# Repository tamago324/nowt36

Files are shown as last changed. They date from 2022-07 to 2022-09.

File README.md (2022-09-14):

# nowt36

以下の特徴を持ったキーボードです。

* 自然と手が置ける配列
* 一体型だけど分割型
* 片手5列
* ホットスワップ対応
* ミドルアクリルプレート対応 (オプション)
* アンダーグロー対応 (オプション)

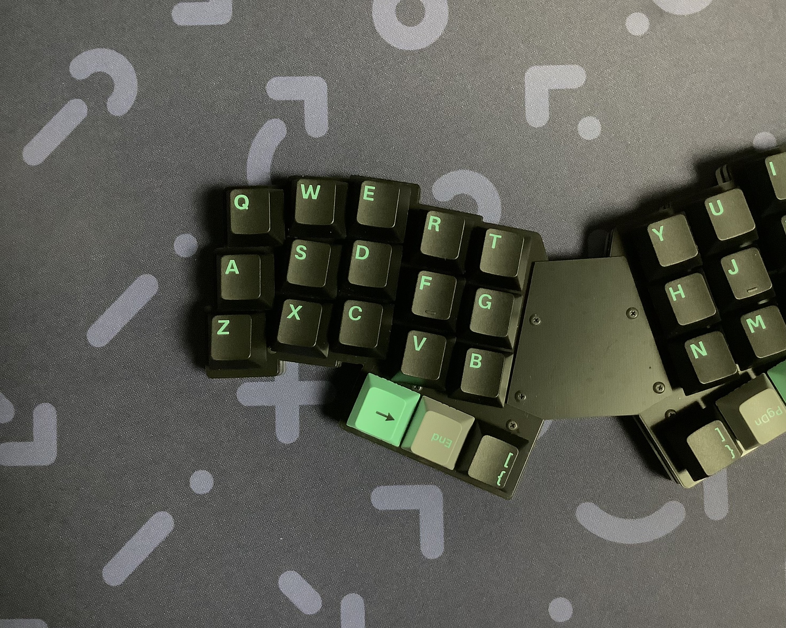
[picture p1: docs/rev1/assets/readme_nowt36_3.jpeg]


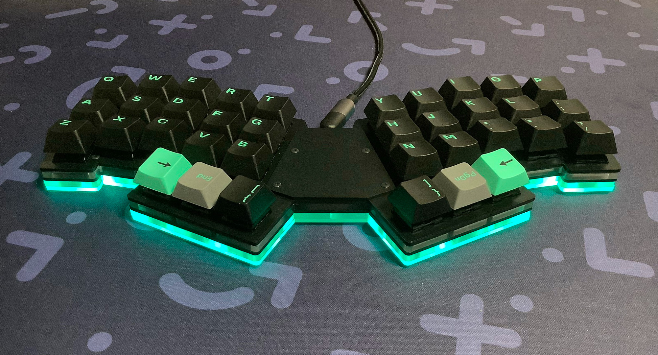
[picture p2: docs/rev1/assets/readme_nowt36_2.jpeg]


## LICENSE

<br />この 作品 は <a rel="license" href="http://creativecommons.org/licenses/by/4.0/">クリエイティブ・コモンズ 表示 4.0 国際 ライセンス</a>の下に提供されています。

> 帰属—適切なクレジットを表示し、ライセンスへのリンクを提供し、変更が行われたかどうかを示す必要があります。

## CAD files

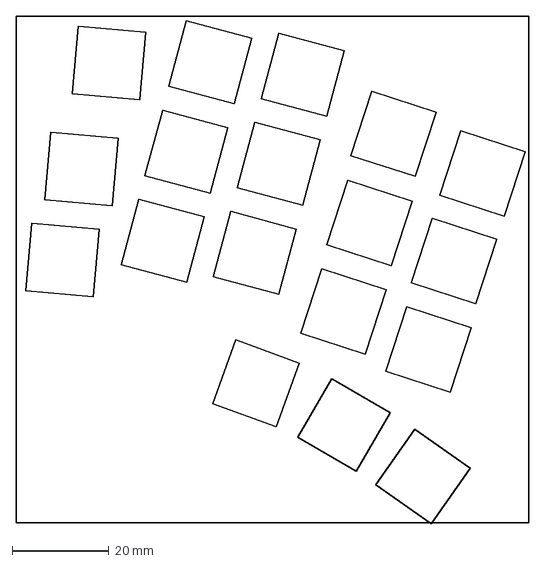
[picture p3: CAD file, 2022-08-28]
data/rev1/plate_base.dxf
105.8 x 104.8 mm

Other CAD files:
data/rev1/nowt36.FCStd

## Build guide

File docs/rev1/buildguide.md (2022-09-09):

# nowt36 ビルドガイド

nowt36 のビルドガイドです。

<details><summary>目次</summary><div>

<!-- vim-markdown-toc GFM -->

* [キットに含まれるもの](#キットに含まれるもの)
* [キット以外に必要なもの](#キット以外に必要なもの)
* [組み立て順序の確認](#組み立て順序の確認)
* [組み立て](#組み立て)
  * [1. ファームウェアの書き込み](#1-ファームウェアの書き込み)
    * [Remap で書き込む場合](#remap-で書き込む場合)
    * [LED の動作確認のため、LED機能をONにします。](#led-の動作確認のためled機能をonにします)
  * [2. (オプション) プレートの側面をペンで塗る](#2-オプション-プレートの側面をペンで塗る)
  * [3. (オプション) LEDの取り付け](#3-オプション-ledの取り付け)
  * [4. ダイオードのはんだ付け](#4-ダイオードのはんだ付け)
  * [5. ホットスワップソケットのはんだ付け](#5-ホットスワップソケットのはんだ付け)
  * [6. リセットスイッチのはんだ付け](#6-リセットスイッチのはんだ付け)
  * [7. (オプション) ミドルプレート (上) とトッププレートの間にシリコンシートを挟む](#7-オプション-ミドルプレート-上-とトッププレートの間にシリコンシートを挟む)
  * [8. トッププレートの端にスイッチを取り付ける](#8-トッププレートの端にスイッチを取り付ける)
  * [9. PCBにトッププレートとスイッチを取り付ける](#9-pcbにトッププレートとスイッチを取り付ける)
  * [10. ボトムプレートを取り付ける](#10-ボトムプレートを取り付ける)
  * [11. トッププレート側からネジ止めする](#11-トッププレート側からネジ止めする)
  * [12. ProMicro保護プレートを取り付ける](#12-promicro保護プレートを取り付ける)
  * [13. ゴム足を取り付ける](#13-ゴム足を取り付ける)
  * [14. キーキャップを取り付ける](#14-キーキャップを取り付ける)
  * [15. キーマップを変更する](#15-キーマップを変更する)
* [最後に](#最後に)

<!-- vim-markdown-toc -->

</div></details>

## キットに含まれるもの

| No. | 名前 | 数量 | 備考 |
|-----|---|---|---|
| 1 | PCB | 1枚 | メインPCB |
| 2 | トッププレート | 1枚 | スイッチをはめるFR4プレート |
| 3 | ボトムプレート | 1枚 | ボトムアクリルプレート |
| 8 | ProMicro 保護プレート | 1枚 | ProMicro 保護プレート。 |
| 9 | スイッチソケット | 36個 | [Kailh Switch Socket](https://shop.yushakobo.jp/products/a01ps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) |
| 10  | ダイオード | 36個 + 予備 | [1N4148W](https://shop.yushakobo.jp/collections/all-keyboard-parts/products/a0800di-02-100) |
| 11  | リセットスイッチ | 1個 | [タクトスイッチ](https://shop.yushakobo.jp/collections/all-keyboard-parts/products/a0800ts-01-1?variant=37665574977697) |
| 12  | M2 スペーサー 8mm (短いもの) | 10個 | トッププレートとボトムプレートを固定するためのスペーサー |
| 13  | M2 スペーサー 9.5mm (長いもの) | 4個 | ProMicro保護プレートとボトムプレートを固定するためのスペーサー |
| 14  | M2 ねじ 5mm | 28個 + 予備 | スペーサーを固定するネジ |
| 15  | アンダーグロー用LED | 10個 | [WS2812B](https://shop.yushakobo.jp/products/a0800ws-01-10?variant=37664848969889) |
| 16  | ゴム足 | 10個 | すべり止め用のゴム足 |

## キット以外に必要なもの

| 名前 | 数量 | 備考 |
|---|---|---|
| キースイッチ | 36個 | - |
| キーキャップ | 36個 | - |
| USBケーブル | 1個  | - |
| ProMicro | 1個  | - |
| コンスルー or ピンヘッダ | 2枚  | 高さが2.5mm以下のものを使用する必要があります。 |

オプションでミドルプレートをつけられます。

| 名前 | 数量 | 備考 |
|---|---|---|
| ミドルプレート (上) | 1枚 | ※1 |
| ミドルプレート (下) | 1枚 | ※1 |
| シリコンシート 0.5mm | 1枚 | トッププレートとミドルプレート (上) の間に挟むシリコンシート。[モノタロウなどで購入](https://www.monotaro.com/g/00279214/?monotaroNo=36295253) |
| シリコンカットサポートシート | 1枚 | シリコンシートを切り抜くときに使用する紙。([こちら](/data/rev1/silicon_cut_sheet/silicon_cut_sheet.svg)を印刷します。) |

※1 [こちら](https://shop.yushakobo.jp/collections/services/products/keyboard_acrylic_plate?variant=44579876995303)から遊舎工房で発注可能です。もとのデータは [こちら](/data/rev1/plate_data/middle_plate) にあるため、自由に加工しAnymanyさんのような他の業者に発注することも可能です。(厚さは **3mm** で発注してください。)

## 組み立て順序の確認

0. キットの内容物の確認
1. ファームウェアの書き込み
2. (オプション) プレートの側面をペンで塗る
3. (オプション) LEDの取り付け
4. ダイオードのはんだ付け
5. ホットスワップソケットのはんだ付け
6. リセットスイッチのはんだ付け
7. (オプション) ミドルプレート (上) とトッププレートの間にシリコンシートを挟む
8. トッププレートの端にスイッチを取り付ける
9. PCBにトッププレートとスイッチを取り付ける
10. ボトムプレートを取り付ける
11. トッププレート側からネジ止めする
12. ProMicro保護プレートを取り付ける
13. ゴム足を取り付ける
14. キーキャップを取り付ける
15. キーマップを変更する

## 組み立て

### 1. ファームウェアの書き込み

REMAP か [QMK](https://github.com/tamago324/qmk_firmware/tree/nowt36/keyboards/tamago324/nowt36) を使用して、ファームウェアを書き込みます。
LEDをはんだ付けする前に Remap でファームウェアを書き込んでおくことで、LED の取付時に1つ1つ確認することができます。

<details><summary>Remap で書き込む場合</summary><div>

#### Remap で書き込む場合

LED を取り付ける場合、Remap でファームウェアを書き込み、LED機能をONにしておくとLEDが正しくはんだ付けできているかの確認が簡単になるのでおすすめです。

> サリチル酸さんの[こちら](https://salicylic-acid3.hatenablog.com/entry/remap-manual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,%E3%83%95%E3%82%A1%E3%83%BC%E3%83%A0%E3%82%A6%E3%82%A7%E3%82%A2%E3%82%92%E6%9B%B8%E3%81%8D%E8%BE%BC%E3%82%80,-%E3%82%AD%E3%83%BC%E3%83%9C%E3%83%BC%E3%83%89%E3%82%AB%E3%82%BF%E3%83%AD%E3%82%B0%E6%A9%9F%E8%83%BD)の記事を参考に手順を記述しています。

https://remap-keys.app/ にアクセスします。 

KEYBOARD CATALOG をクリックします。

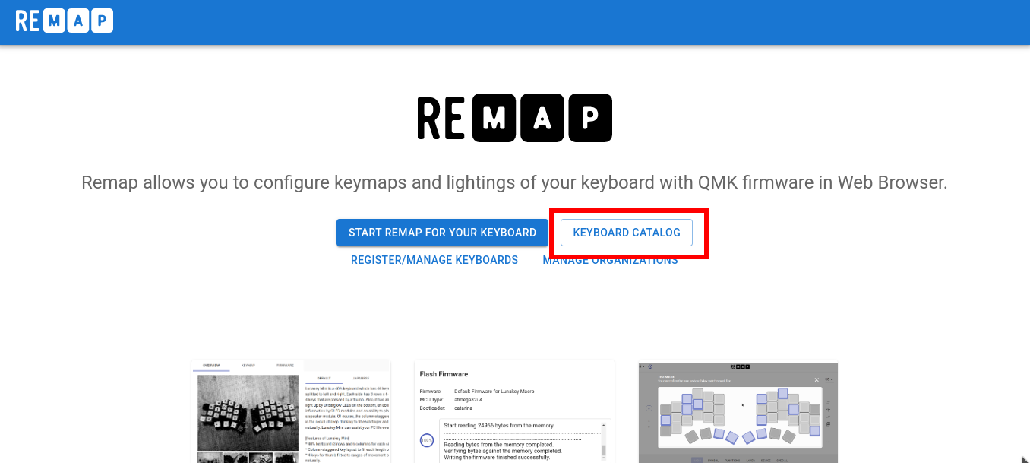
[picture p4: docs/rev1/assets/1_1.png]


Keyboard name の入力欄に `nowt36` と入力し、Search をクリックし、検索結果の nowt36 をクリックします。

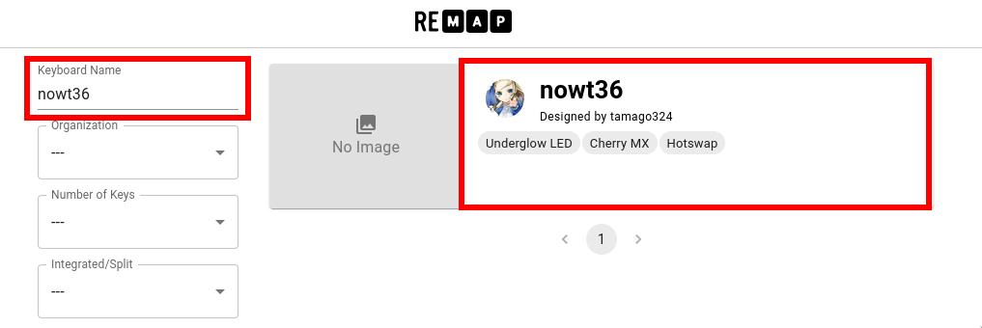
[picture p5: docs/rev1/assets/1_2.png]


FIRMWARE をクリックします。

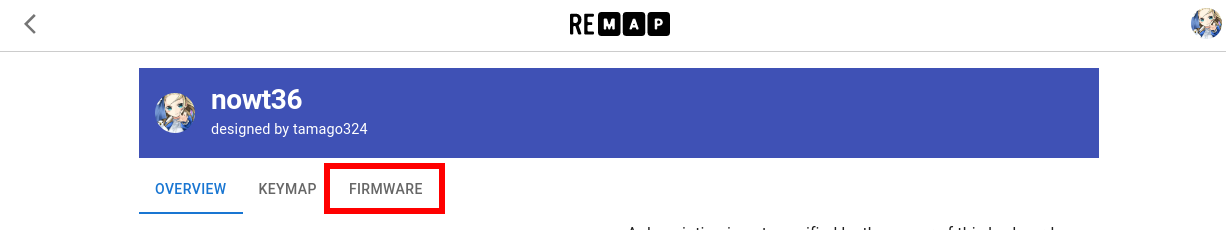
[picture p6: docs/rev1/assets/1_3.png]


FLASH をクリック

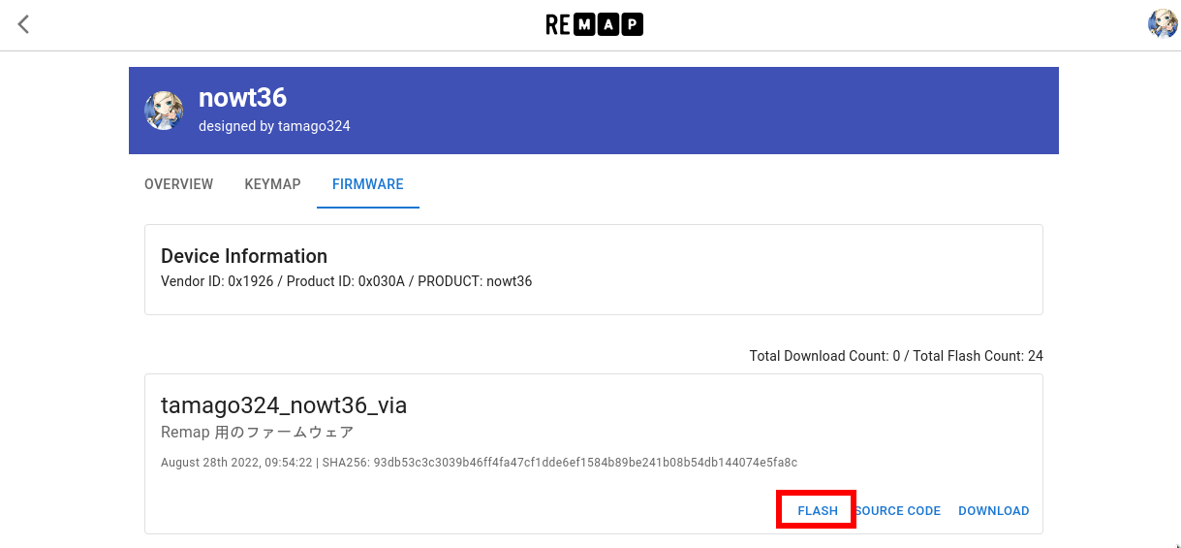
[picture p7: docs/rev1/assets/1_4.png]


ダイアログが表示されたら FLASH をクリックします。

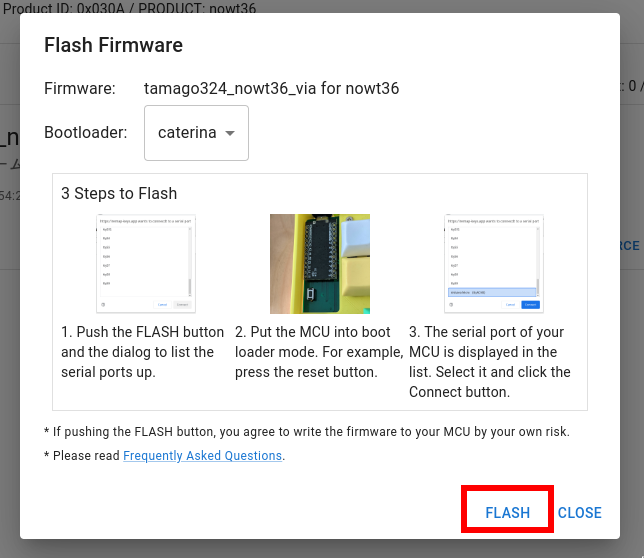
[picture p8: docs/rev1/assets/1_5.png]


remap-keys.app がシリアルポートへの接続を要求しています という表示が出たら、ピンセットでProMicro の`GND`と`RST`を2回素早く押します。

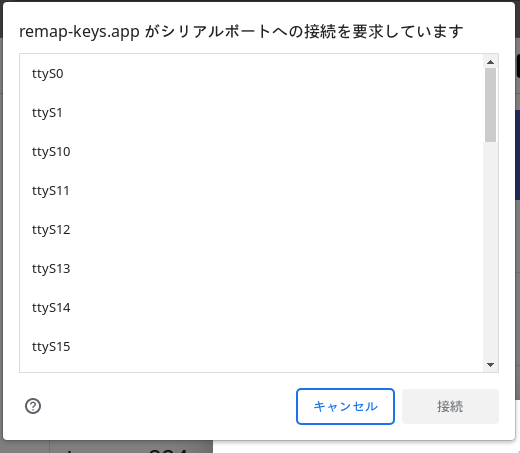
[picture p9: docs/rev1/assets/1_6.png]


ProMicro が表示されたら、それを選択し、接続ボタンをクリックします。  

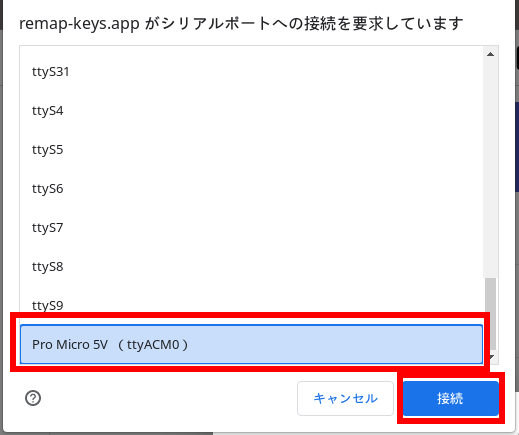
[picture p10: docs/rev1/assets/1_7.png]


少し時間が立つとファームウェアの書き込みが完了します。

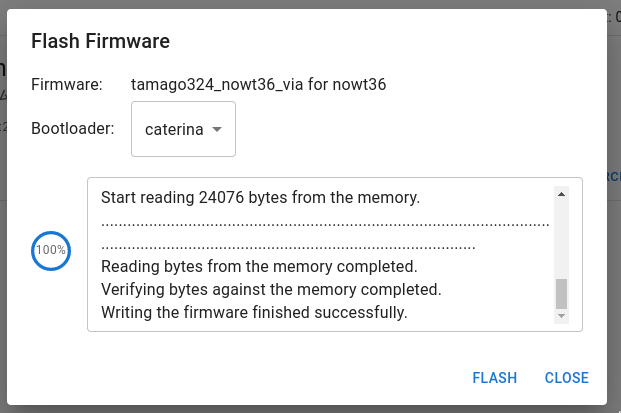
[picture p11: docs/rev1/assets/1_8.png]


#### LED の動作確認のため、LED機能をONにします。

https://remap-keys.app/ にアクセスします。

`START REMAP FOR YOUR KEYBOARD` をクリックします。

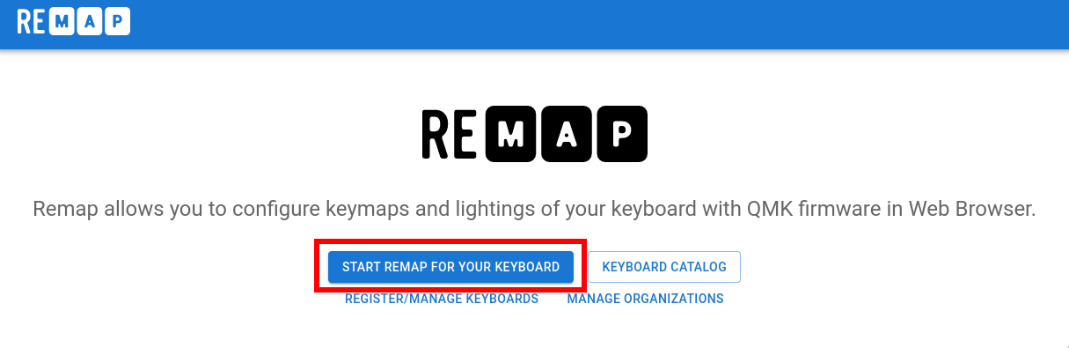
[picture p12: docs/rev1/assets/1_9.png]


`+ KEYBAORD` をクリックします。

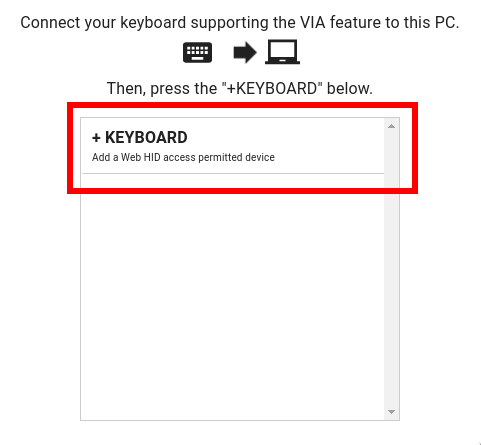
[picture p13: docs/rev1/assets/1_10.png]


`tamago324 nowt36` をクリックします。

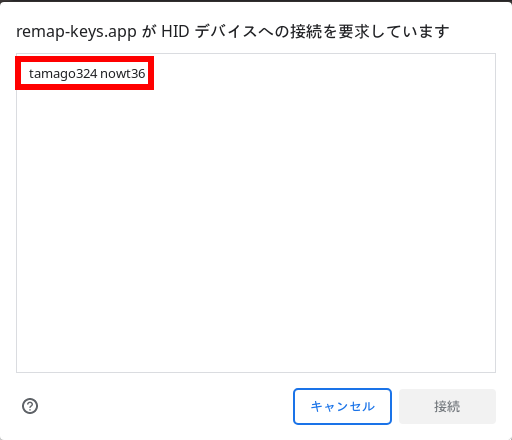
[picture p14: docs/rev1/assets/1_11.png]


`Lightning` をクリック、

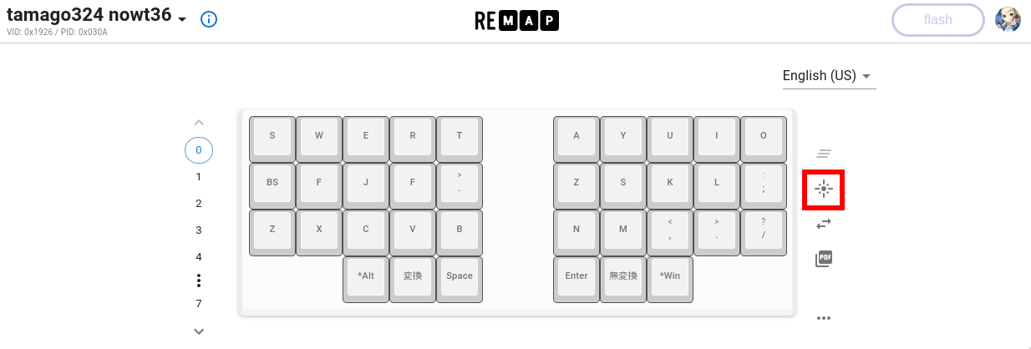
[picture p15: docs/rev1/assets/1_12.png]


`EffectMode` を `Solid color` を選択します。

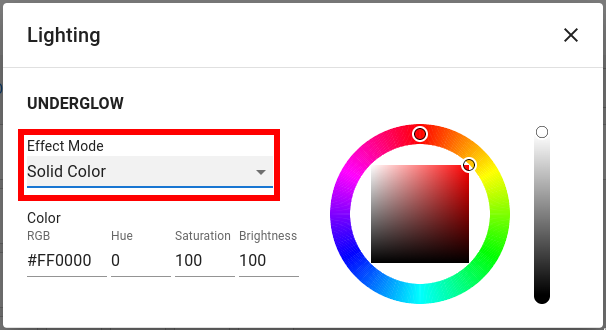
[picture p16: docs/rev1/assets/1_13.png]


以上で、LED の確認のためのファームウェアの書き込みは完了です。

</div></details>

### 2. (オプション) プレートの側面をペンで塗る

PCB と ボトムプレートの側面をペンで塗るときれいに仕上げられます。

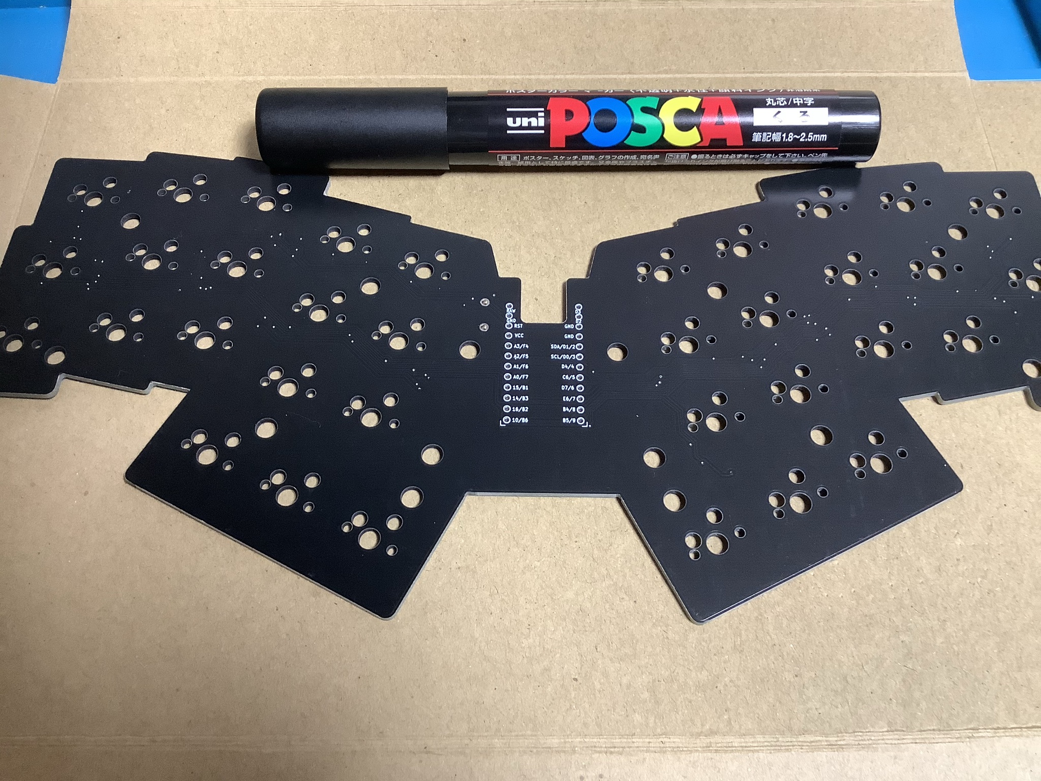
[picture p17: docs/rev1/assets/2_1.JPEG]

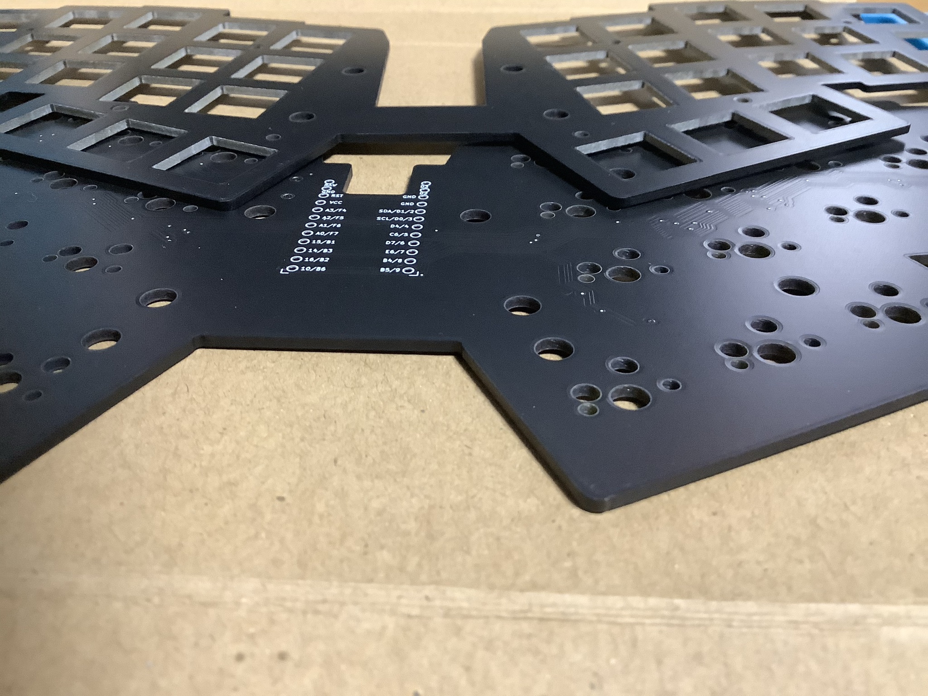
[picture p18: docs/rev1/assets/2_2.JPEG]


### 3. (オプション) LEDの取り付け

PCBの裏の D37 から時計回りにLEDを9個 (D37〜D45) をはんだ付けします。 
PCBの裏のはんだ付けが終わったら PCB の表面の D46 にLEDを1個はんだ付けします。
「PCBのシルクの角」と「LEDのかけている部分」が同じ位置になるようにはんだ付けします。
はんだごての温度は低め (270℃〜300℃) に設定し、作業します。

1つLEDをはんだ付けするたびにUSBを接続し、LED が光ることを確認することをおすすめします。

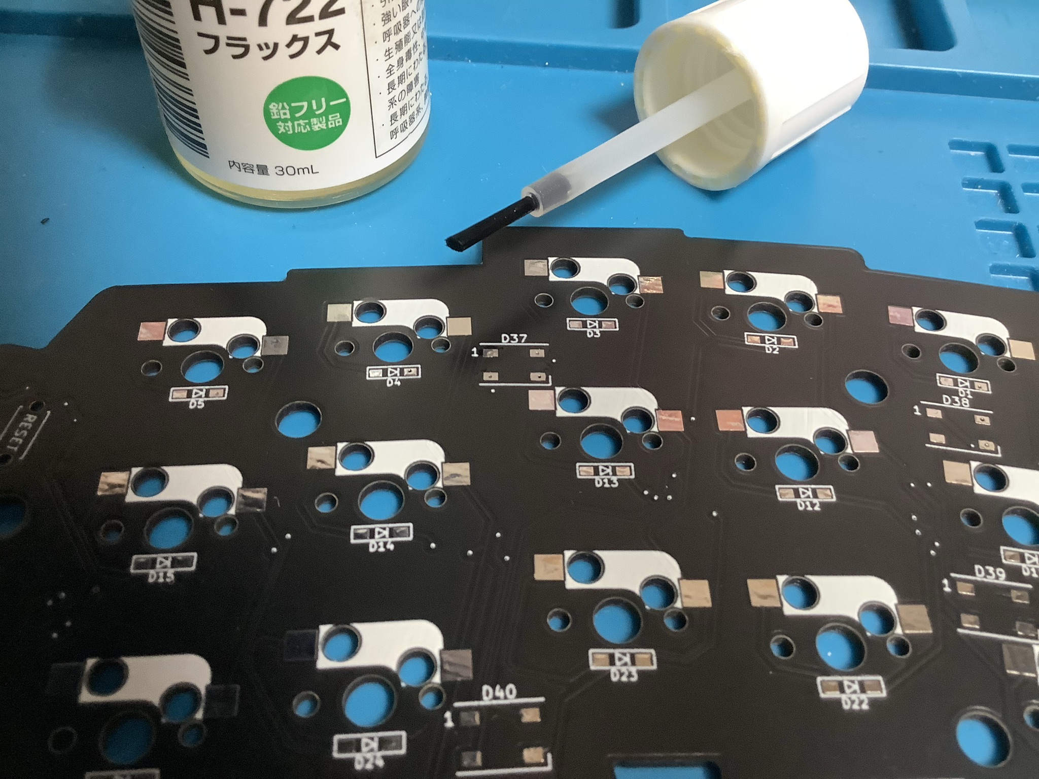
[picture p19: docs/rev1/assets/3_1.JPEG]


PCBのシルクの角 に予備ハンダをします。

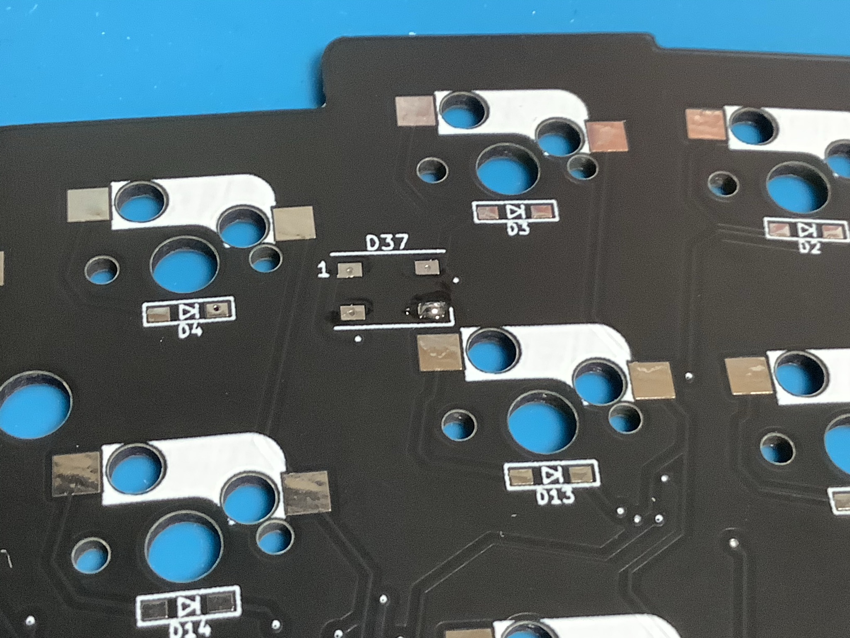
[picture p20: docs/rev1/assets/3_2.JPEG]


PCBのシルクの角 と LEDのかけている部分が同じ位置になるようにはんだ付けします。

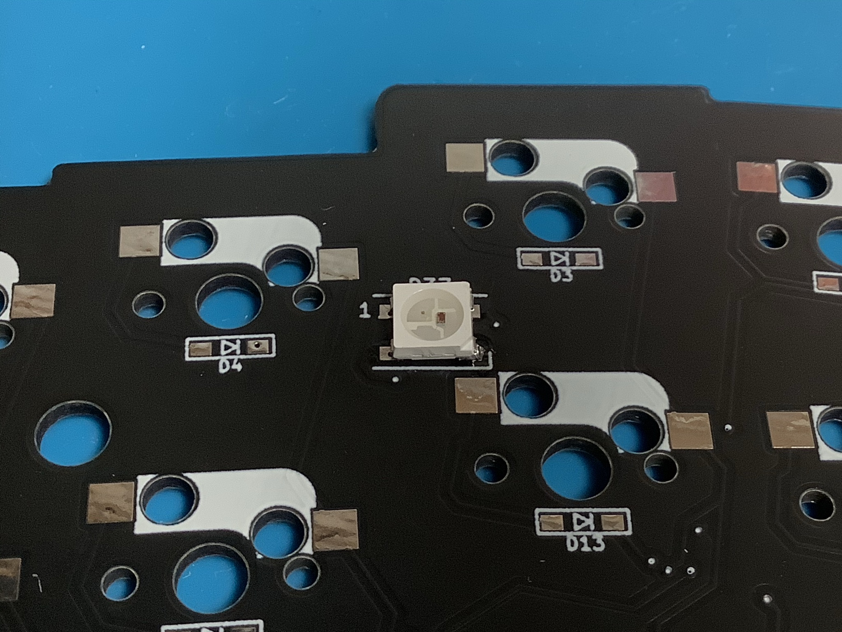
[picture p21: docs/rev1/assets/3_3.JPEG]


それ以外の部分をはんだ付けします。

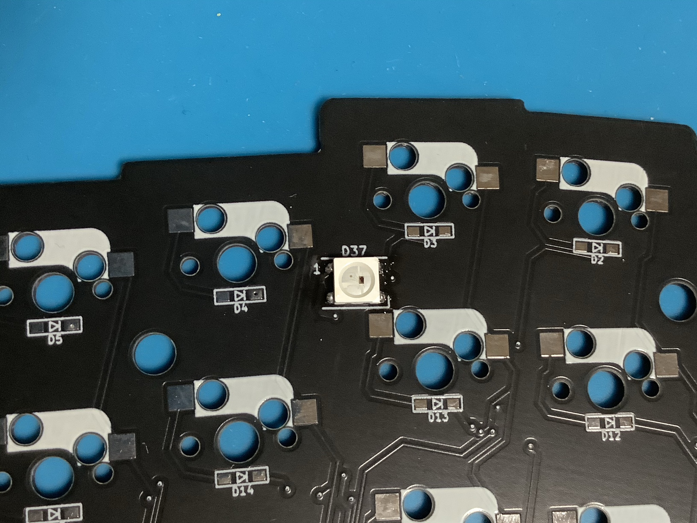
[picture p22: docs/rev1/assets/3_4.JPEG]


4箇所はんだ付けし終わったらUSBを接続し、LEDが光ることを確認します。
(※ REMAP で LED をONにしておくことで簡単に光ることが確認できます。)

また、LED をはんだ付けするときはUSBケーブルを外してください。

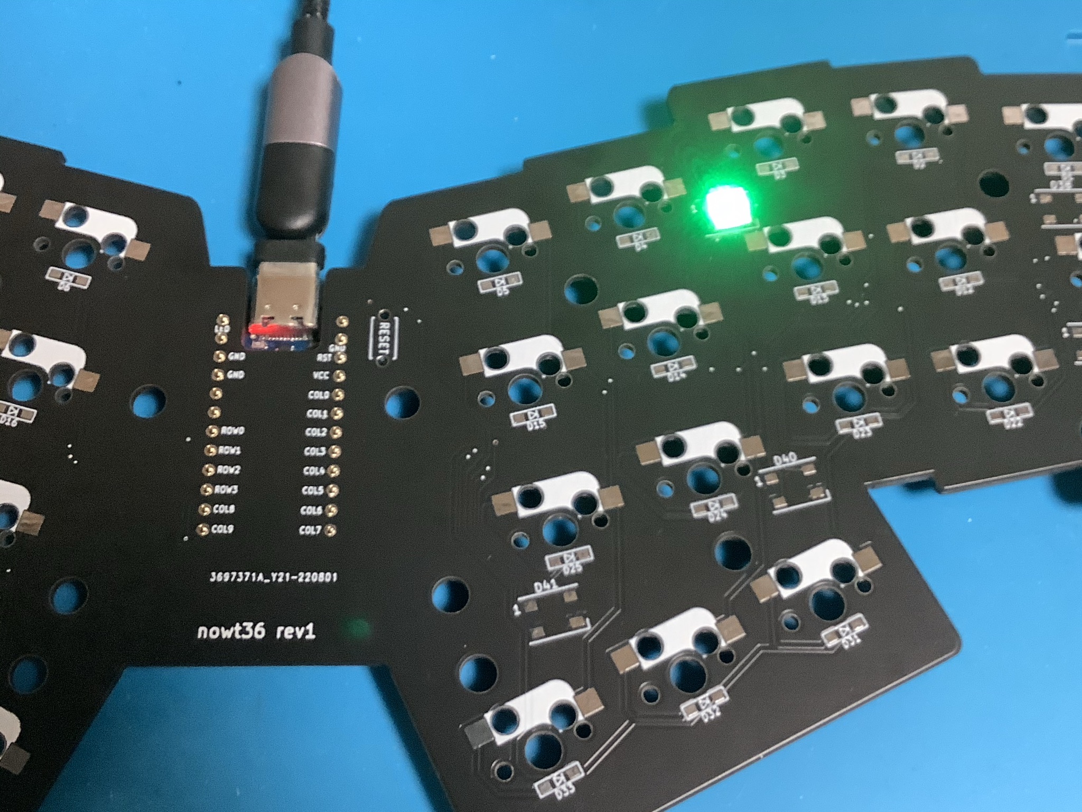
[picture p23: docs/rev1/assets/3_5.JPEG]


10個の LED をはんだ付けします。

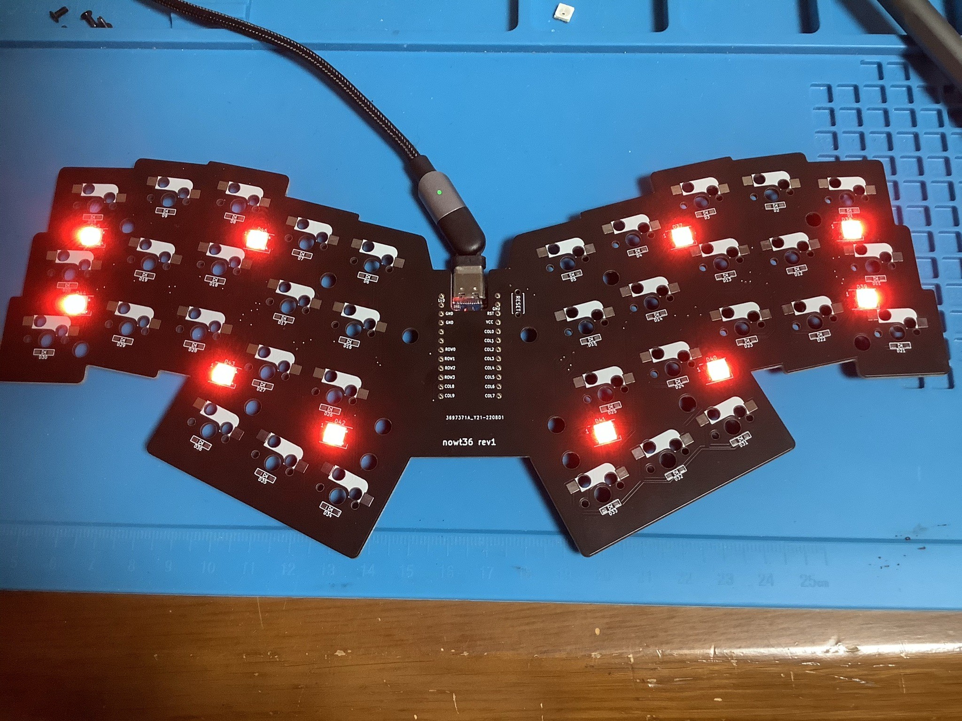
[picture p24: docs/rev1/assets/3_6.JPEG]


### 4. ダイオードのはんだ付け

PCBの裏にダイオードを36個はんだ付けします。
「PCBのシルクの線」と「ダイオードの線」が一致するようにはんだ付けします。
はんだごての温度は320℃くらいに設定し作業します。

片側に予備ハンダを行い、
ピンセットを使用して、はんだ付けを行い、
もう片方もはんだ付けします。

すべてのダイオードのはんだ付けが終わったら、すべてのダイオードが同じ向きになっていることを確認してください。

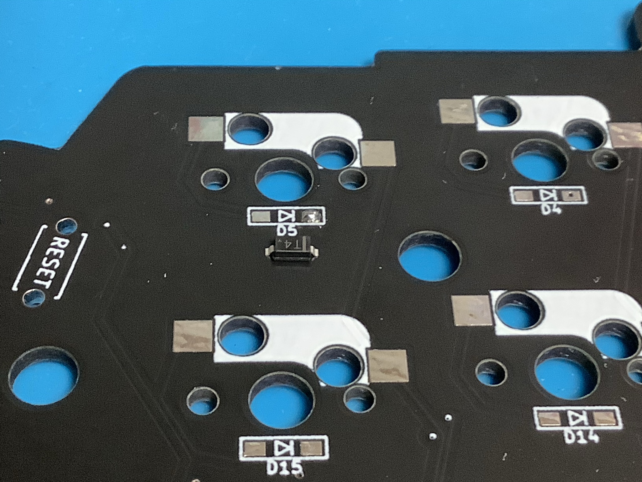
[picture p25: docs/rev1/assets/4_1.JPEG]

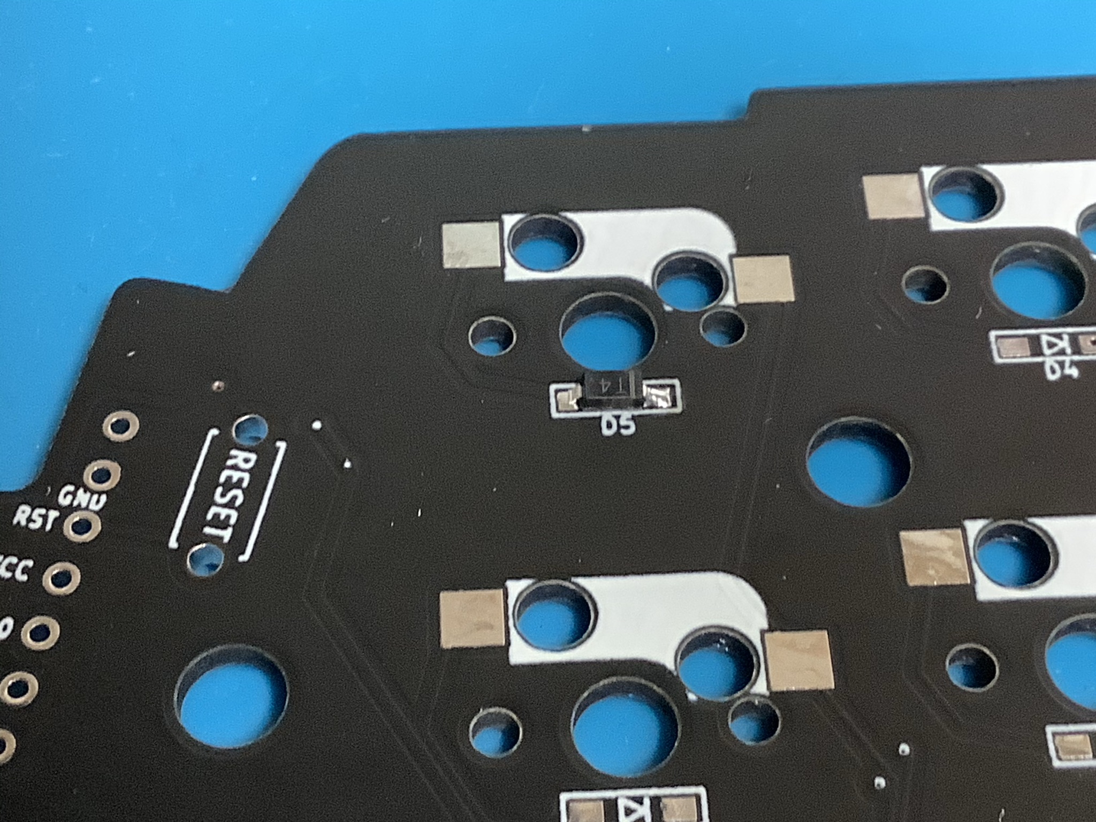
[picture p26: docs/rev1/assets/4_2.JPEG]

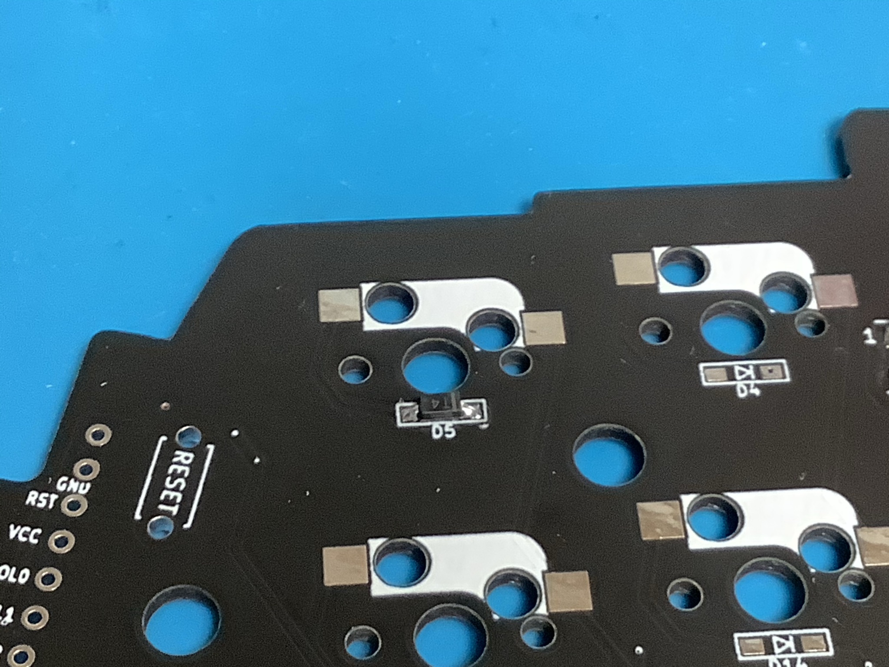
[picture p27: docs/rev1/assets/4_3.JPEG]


### 5. ホットスワップソケットのはんだ付け

PCBの裏にスイッチソケットを36個はんだ付けします。
PCBのシルクが隠れるようにはんだ付けします。
はんだごての温度は320℃くらいに設定し作業します。

片側に予備ハンダを行い、
スイッチソケットを置いて、はんだ付けします。
もう片方もはんだ付けします。

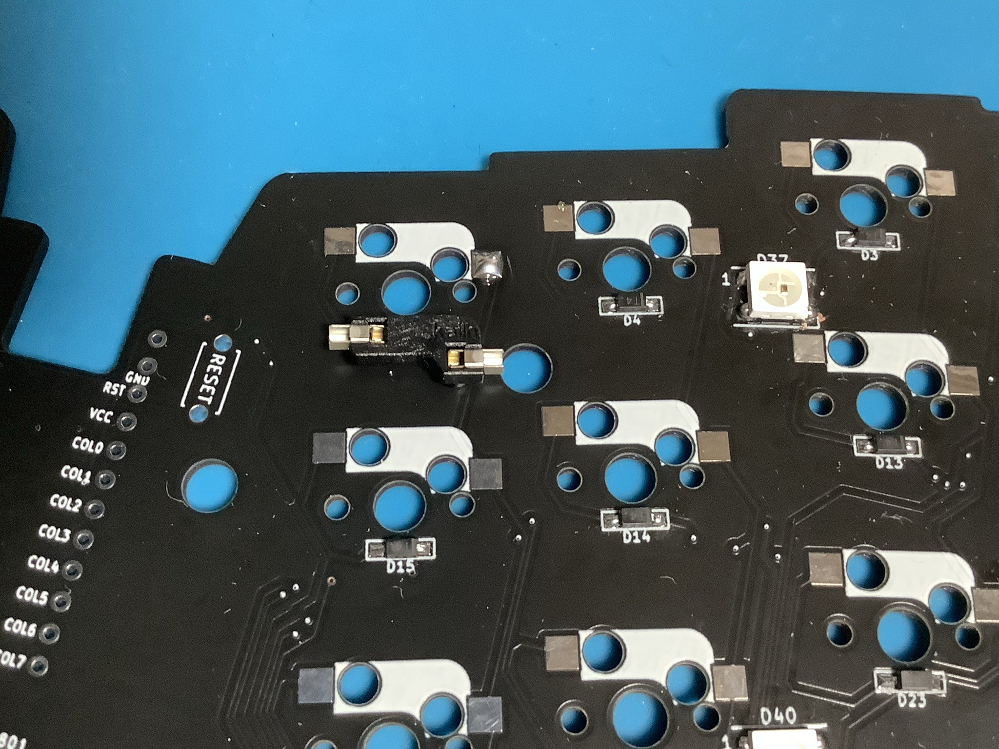
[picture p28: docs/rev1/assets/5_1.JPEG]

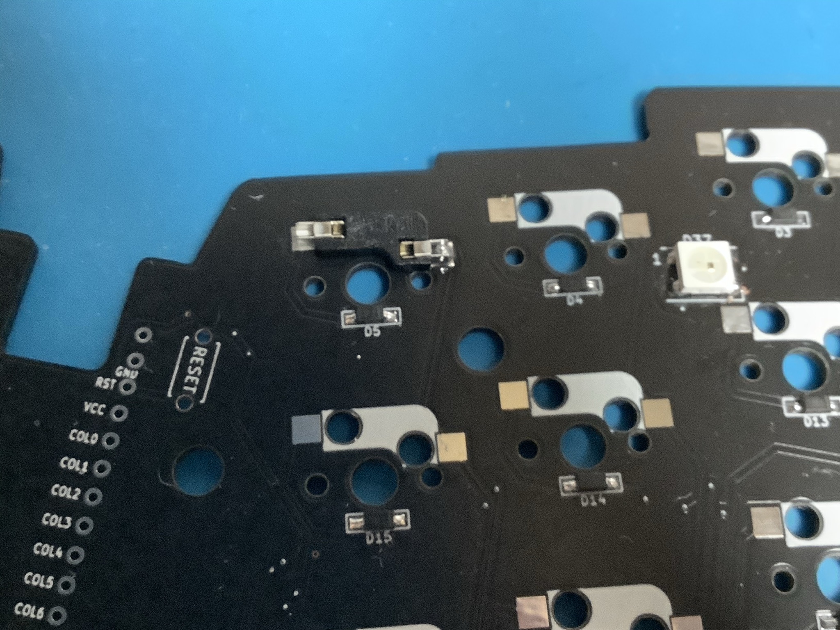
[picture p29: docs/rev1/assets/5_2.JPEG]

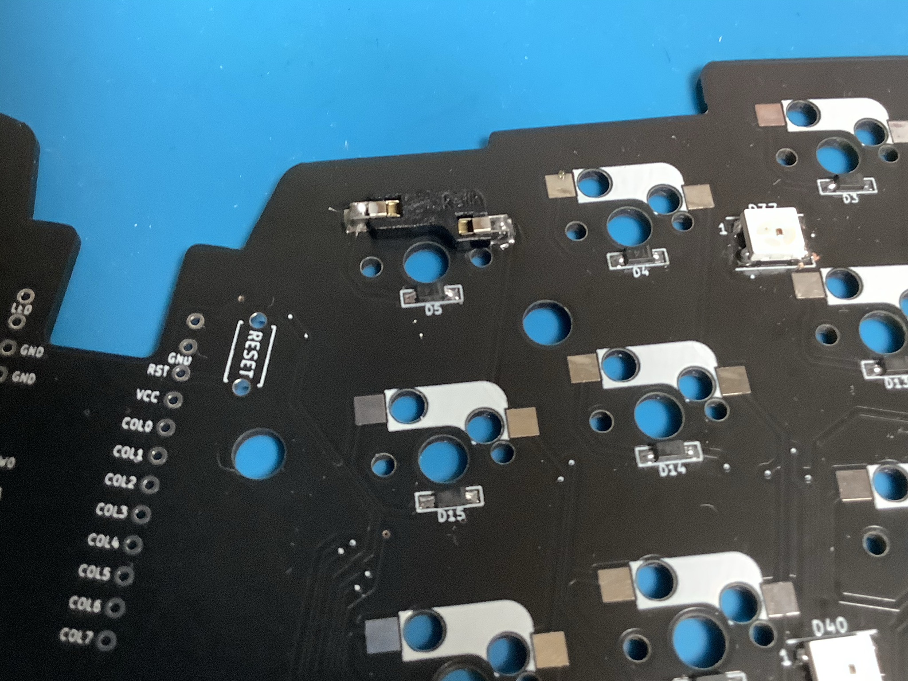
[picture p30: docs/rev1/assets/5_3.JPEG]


### 6. リセットスイッチのはんだ付け

PCBの裏から RESET という文字が隠れるようにリセットスイッチを差し込みます。
PCBの表に出ている足をはんだ付けします。

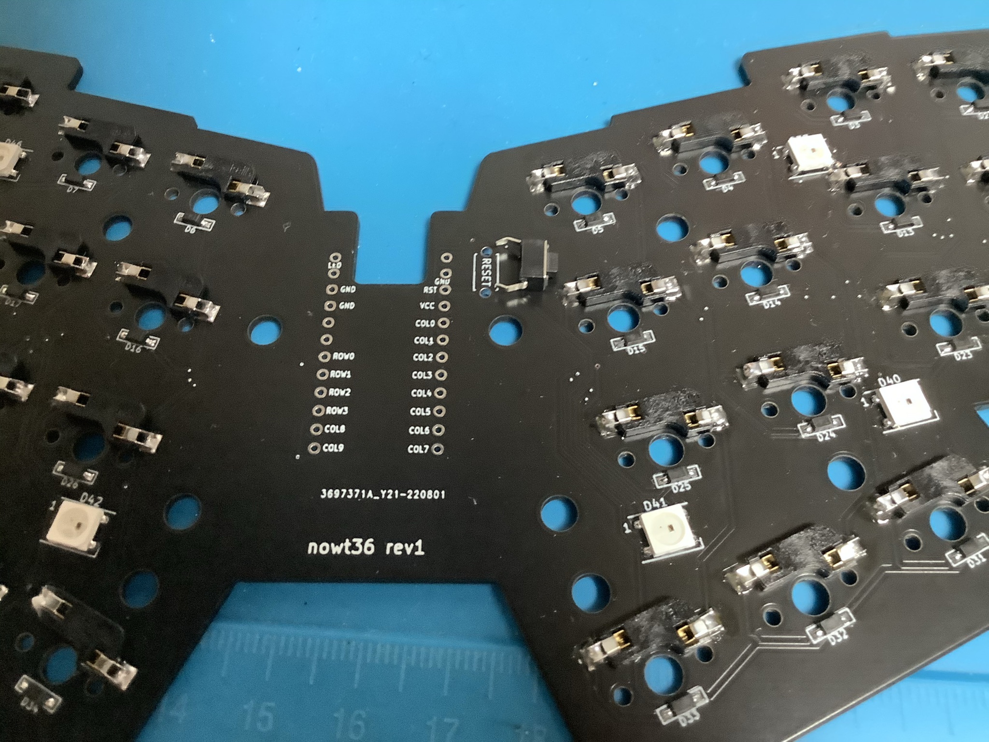
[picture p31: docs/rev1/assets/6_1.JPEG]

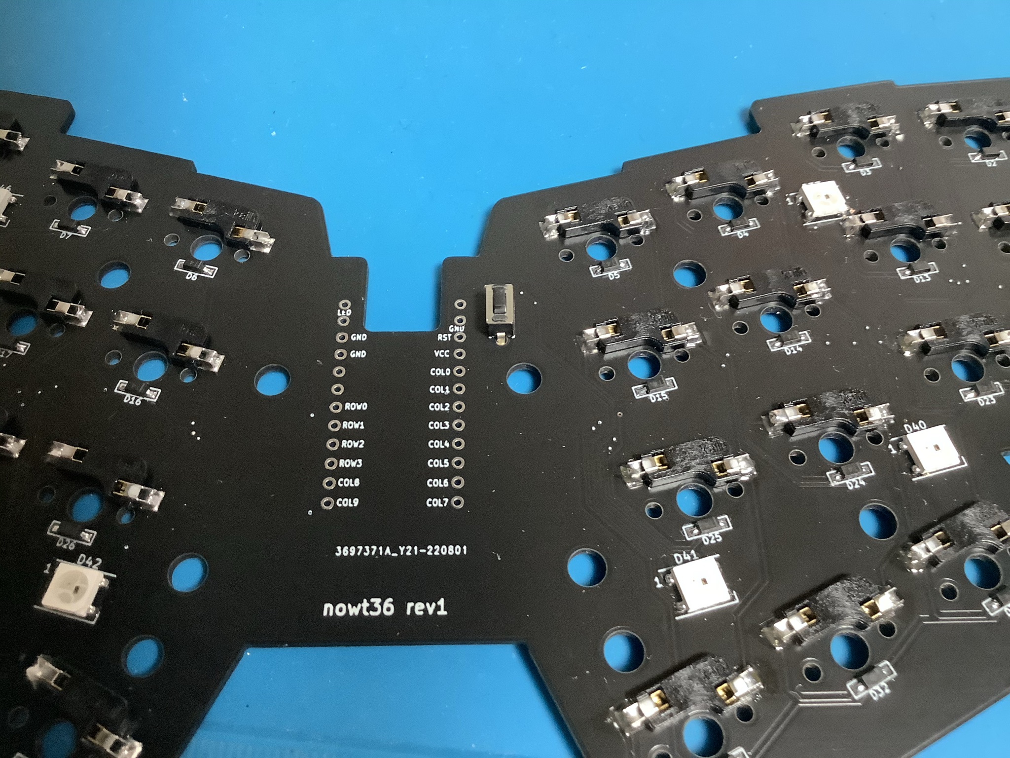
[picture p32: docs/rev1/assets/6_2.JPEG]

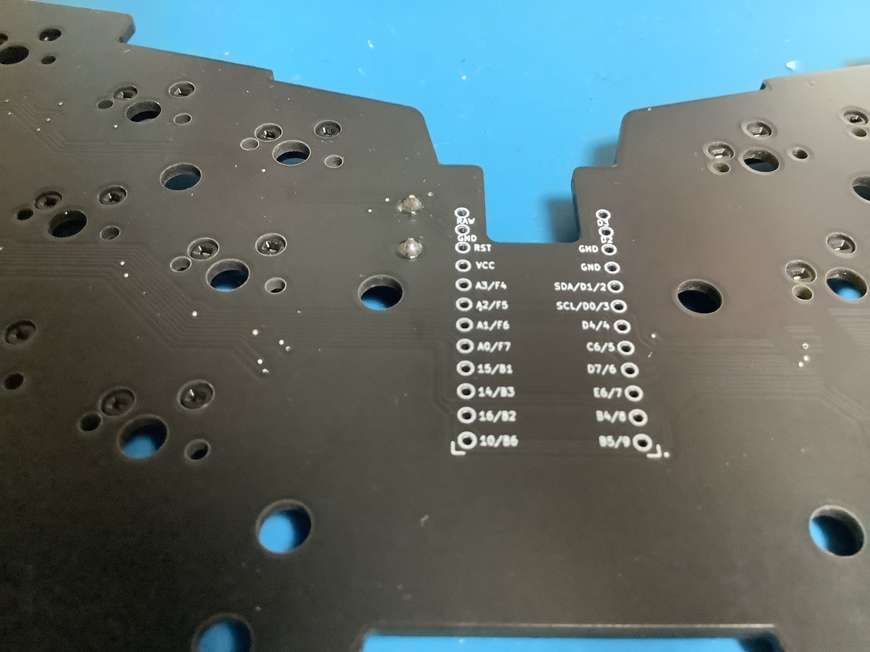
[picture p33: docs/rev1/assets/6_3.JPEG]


### 7. (オプション) ミドルプレート (上) とトッププレートの間にシリコンシートを挟む

オプションでミドルプレートをつけることができます。

<details><summary>手順</summary><div>

[シリコンカットサポートシート](/data/rev1/silicon_cut_sheet/silicon_cut_sheet.svg) をA4用紙で印刷します。

以下の手順でミドルプレート (上) とトッププレートの間にシリコンシートを挟みます。  
最初にシリコンカットサポートシート がミドルプレート (上) と同じサイズで印刷されていることを確認します。  
同じサイズだった場合、以下の手順を実施します。

1. シリコンシートについている保護シートを両面剥がします。

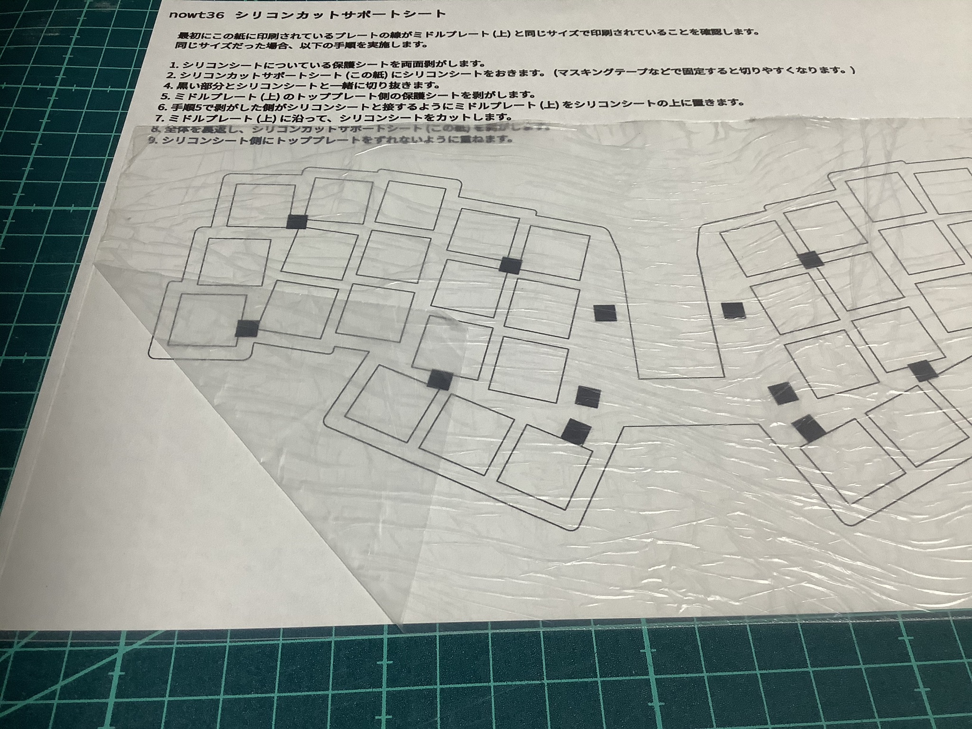
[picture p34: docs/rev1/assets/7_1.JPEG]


2. シリコンカットサポートシートにシリコンシートをおきます。 (マスキングテープなどで固定すると切りやすくなります。)

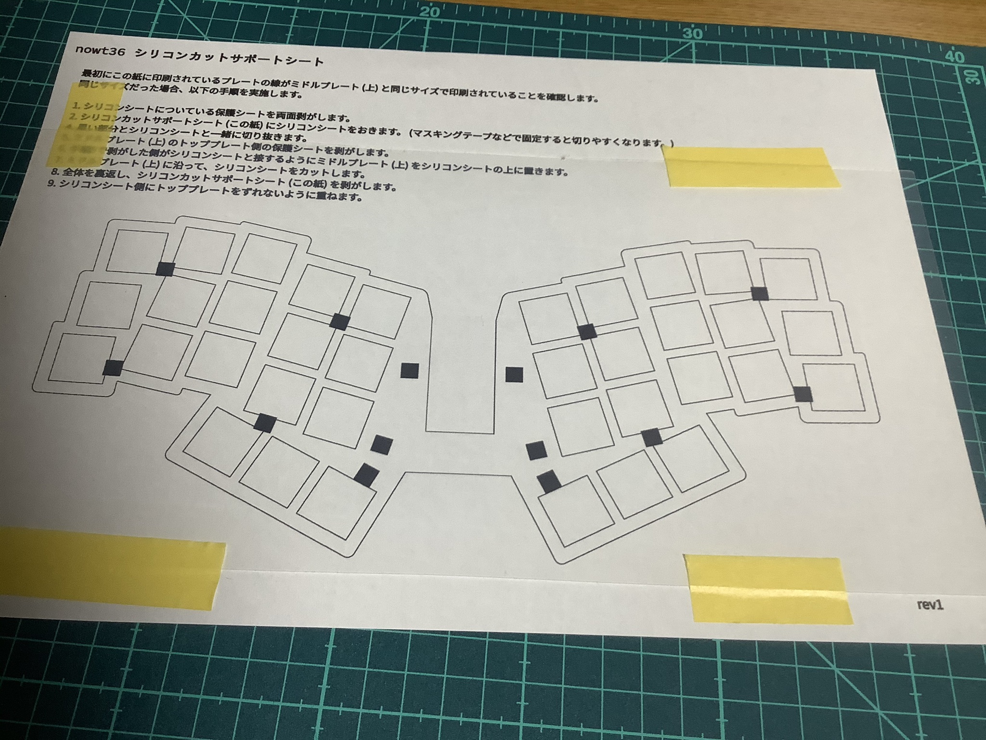
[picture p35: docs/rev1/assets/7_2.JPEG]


3. 黒い部分をシリコンシートと一緒に切り抜きます。

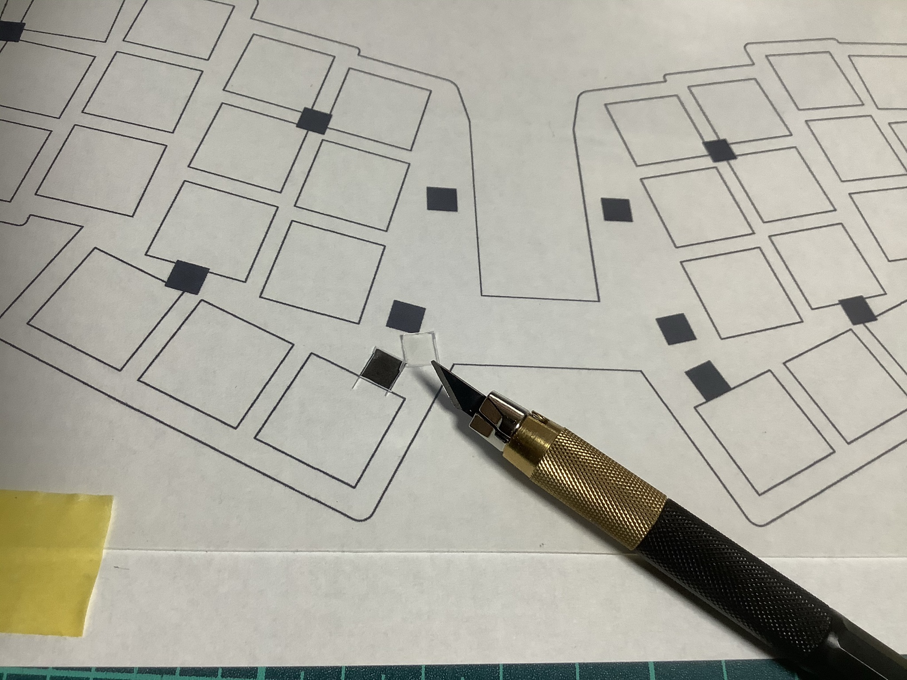
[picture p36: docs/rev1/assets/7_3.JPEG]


4. ミドルプレート (上) のトッププレート側の保護シートを剥がします。

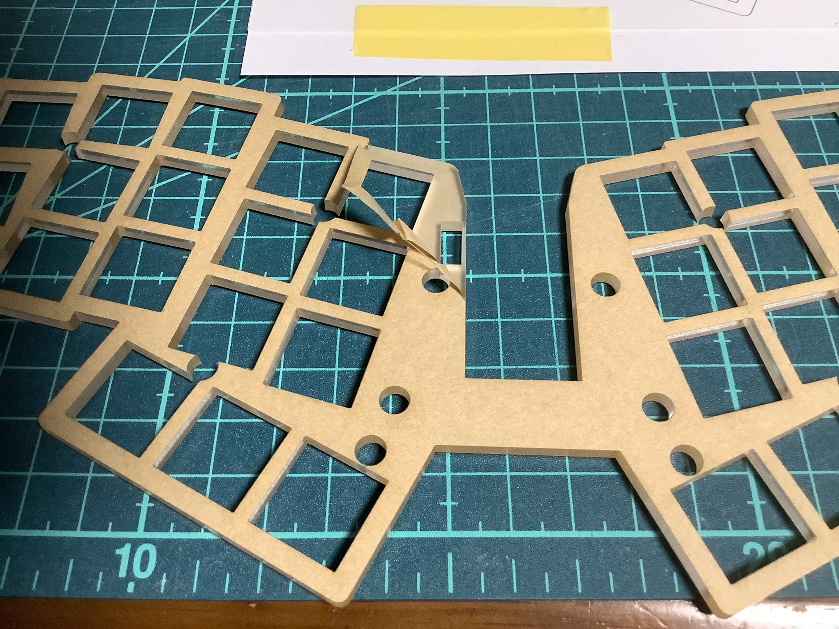
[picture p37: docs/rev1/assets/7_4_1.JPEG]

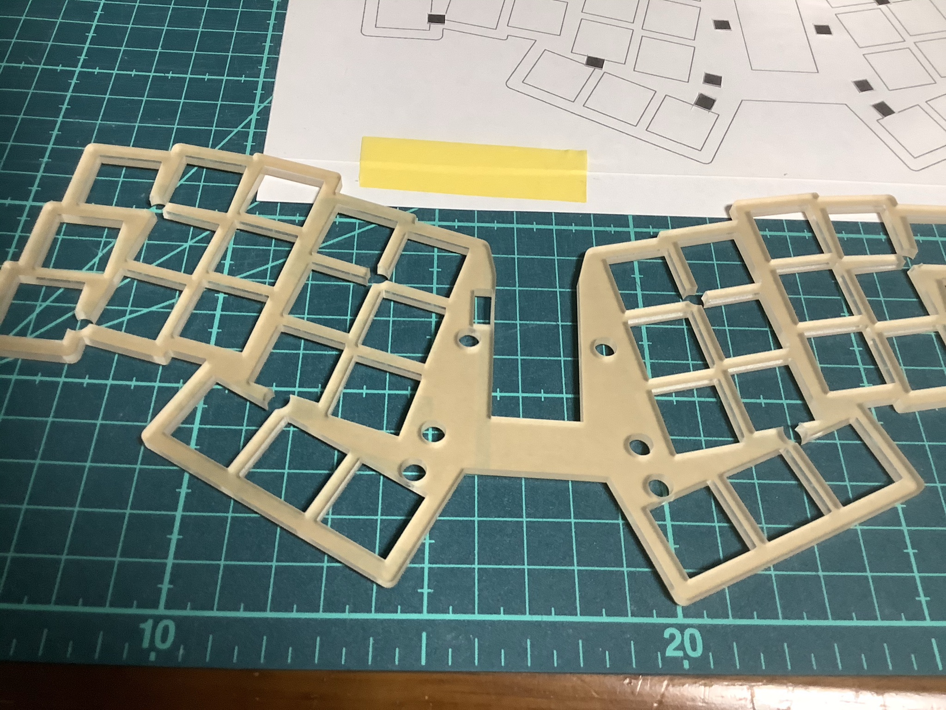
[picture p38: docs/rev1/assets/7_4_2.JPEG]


5. 手順5で剥がした側がシリコンシートと接するようにミドルプレート (上) をシリコンシートの上に置きます。

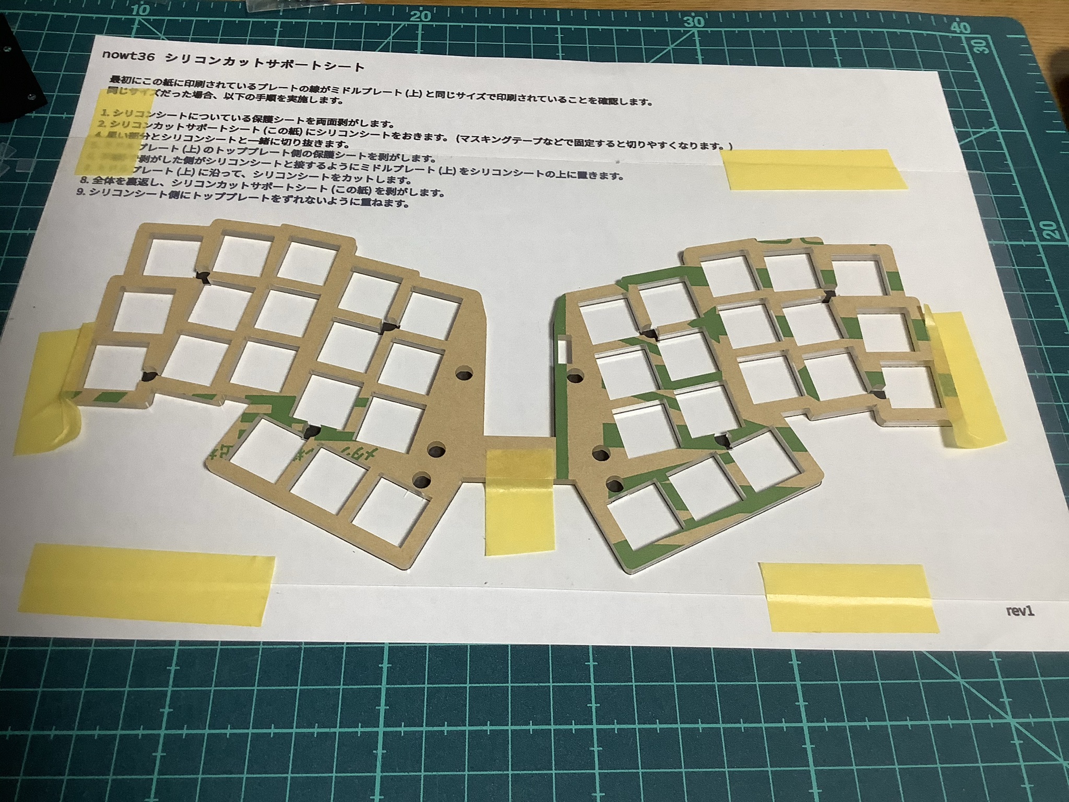
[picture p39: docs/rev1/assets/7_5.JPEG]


6. ミドルプレート (上) に沿って、シリコンシートをカットします。

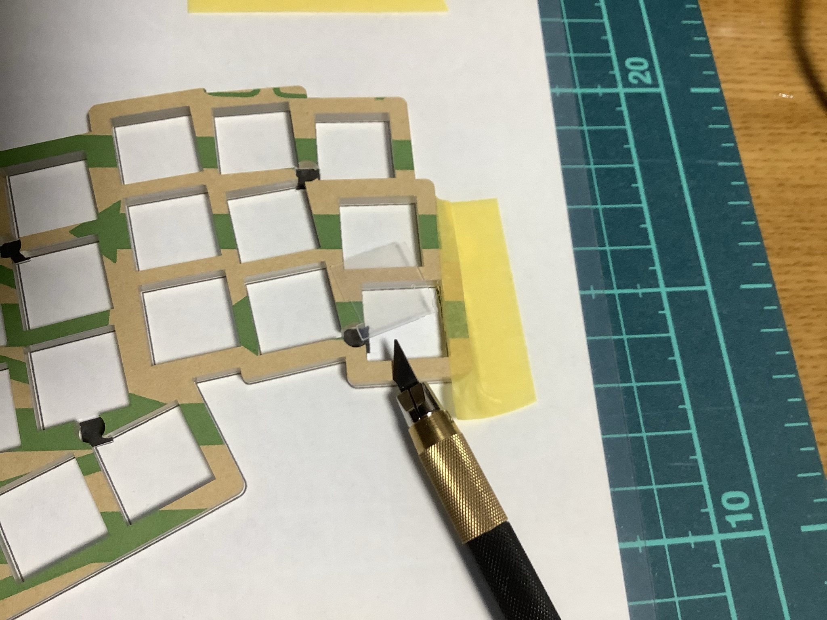
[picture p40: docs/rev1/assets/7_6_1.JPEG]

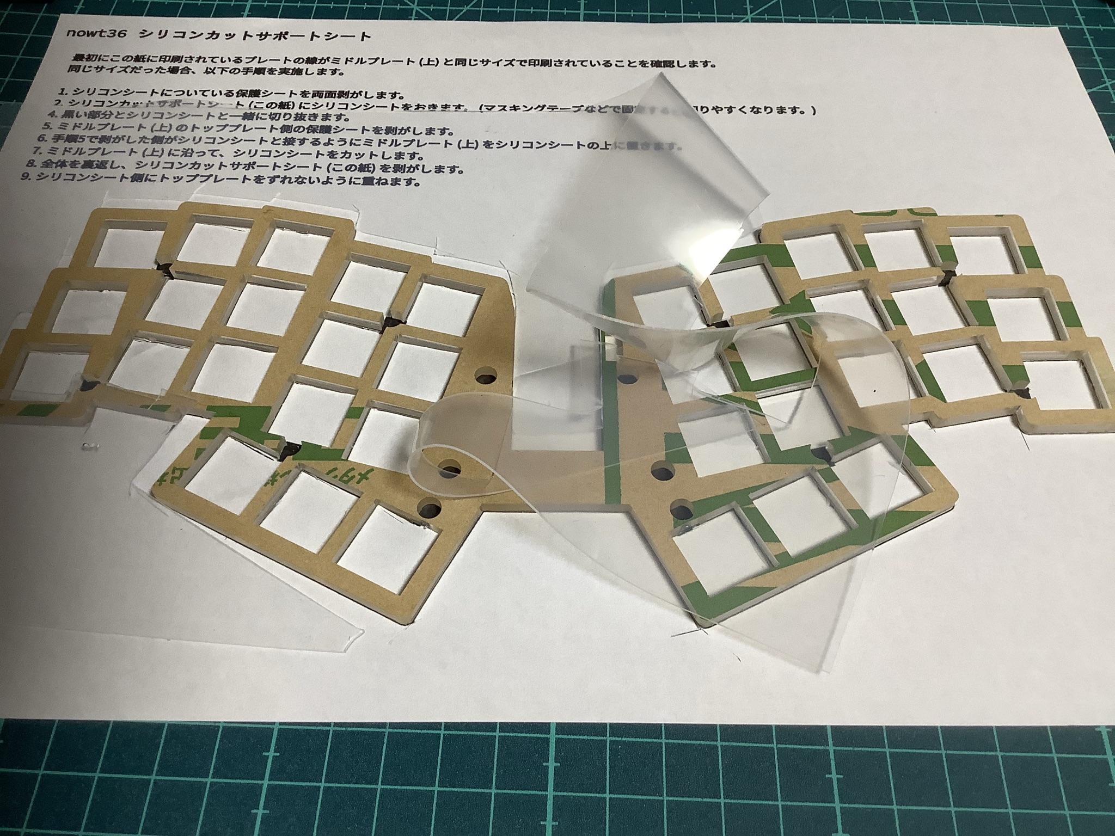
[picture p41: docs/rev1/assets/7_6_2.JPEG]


7. ミドルプレート (上) のもう片方の保護シートを剥がします。 (両方の保護シートが剥がれている状態です。)

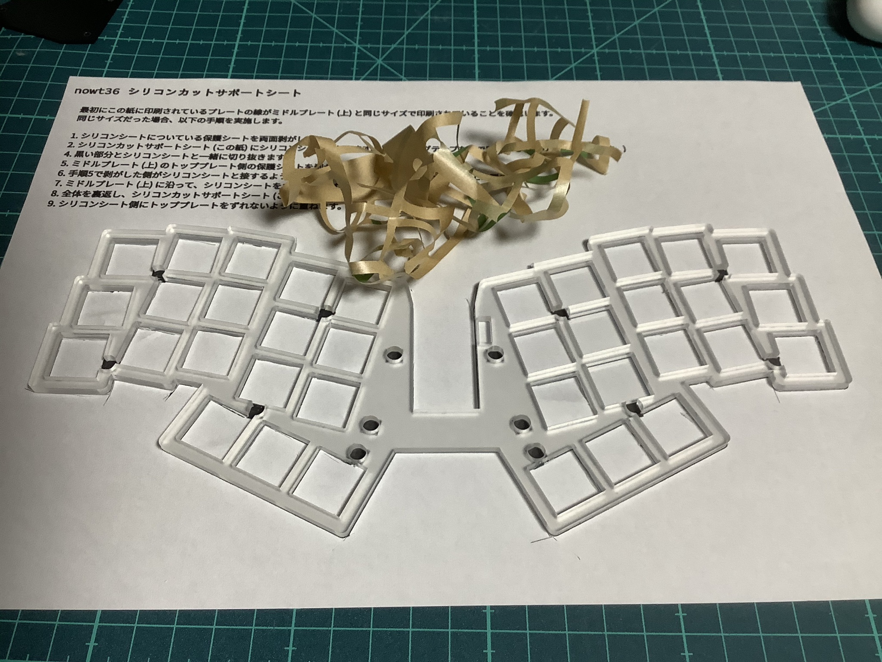
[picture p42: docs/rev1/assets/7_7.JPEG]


8. 全体を裏返し、シリコンカットサポートシートを剥がします。

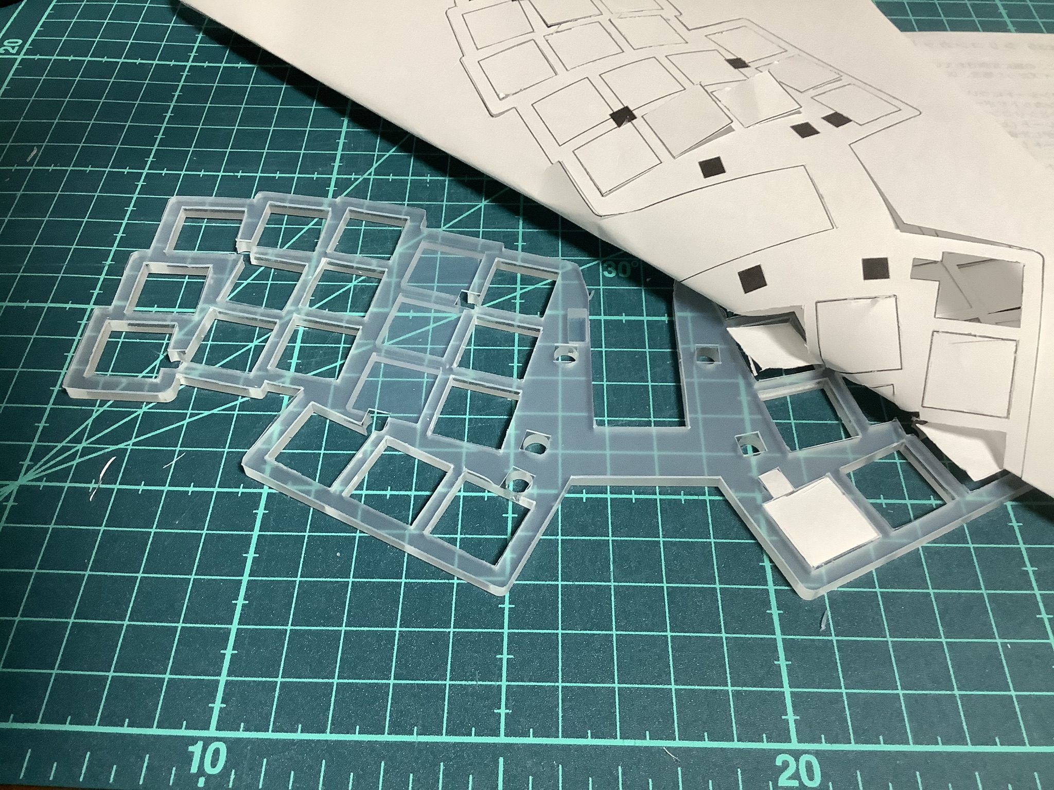
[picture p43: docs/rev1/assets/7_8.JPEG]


9. シリコンシート側にトッププレートをずれないように重ねます。



</div></details>

### 8. トッププレートの端にスイッチを取り付ける

位置合わせのため、トッププレートの端の数カ所ににスイッチを取り付け、PCB のソケットにスイッチが刺さるように合わせます。



### 9. PCBにトッププレートとスイッチを取り付ける

トッププレートをPCBに取り付けます。



スイッチの足が曲がっていないことを確認し、すべてのスイッチを取り付けます。

### 10. ボトムプレートを取り付ける

まず、ボトムプレートにスペーサーを取り付けます。
ProMicro周辺の4つのスペーサーは9.5mmのスペーサーを取り付けます。
それ以外の部分は、8mmのスペーサーを取り付けます。



オプションでボトムプレートの上にミドルプレート (下) を重ねます。



その上にトッププレート+PCB を重ねます。



### 11. トッププレート側からネジ止めする

ProMicro以外の場所をトッププレート側からネジ止めします。




### 12. ProMicro保護プレートを取り付ける

まず、ProMicro のピンをカットします。




PCB に取り付けます。



ProMicro 保護プレートを載せ、ネジ止めします。



### 13. ゴム足を取り付ける

ボトムプレートの裏にゴム足をつけます。



### 14. キーキャップを取り付ける

キーキャップを取り付けます。



### 15. キーマップを変更する

Remap か QMK を使用してキーマップを変更可能です。

* Remap の場合: キーボードカタログの nowt36 のページで設定可能です。
* QMK の場合: [tamago324/qmk_firmware](https://github.com/tamago324/qmk_firmware/tree/nowt36) の `nowt36` ブランチの `keyboards/tamago324/nowt36` にファームウェアがあります。

## 最後に

完成したキーボードの写真を SNS に投稿していただけるととても嬉しいです！
(ハッシュタグは `#nowt36` です。)

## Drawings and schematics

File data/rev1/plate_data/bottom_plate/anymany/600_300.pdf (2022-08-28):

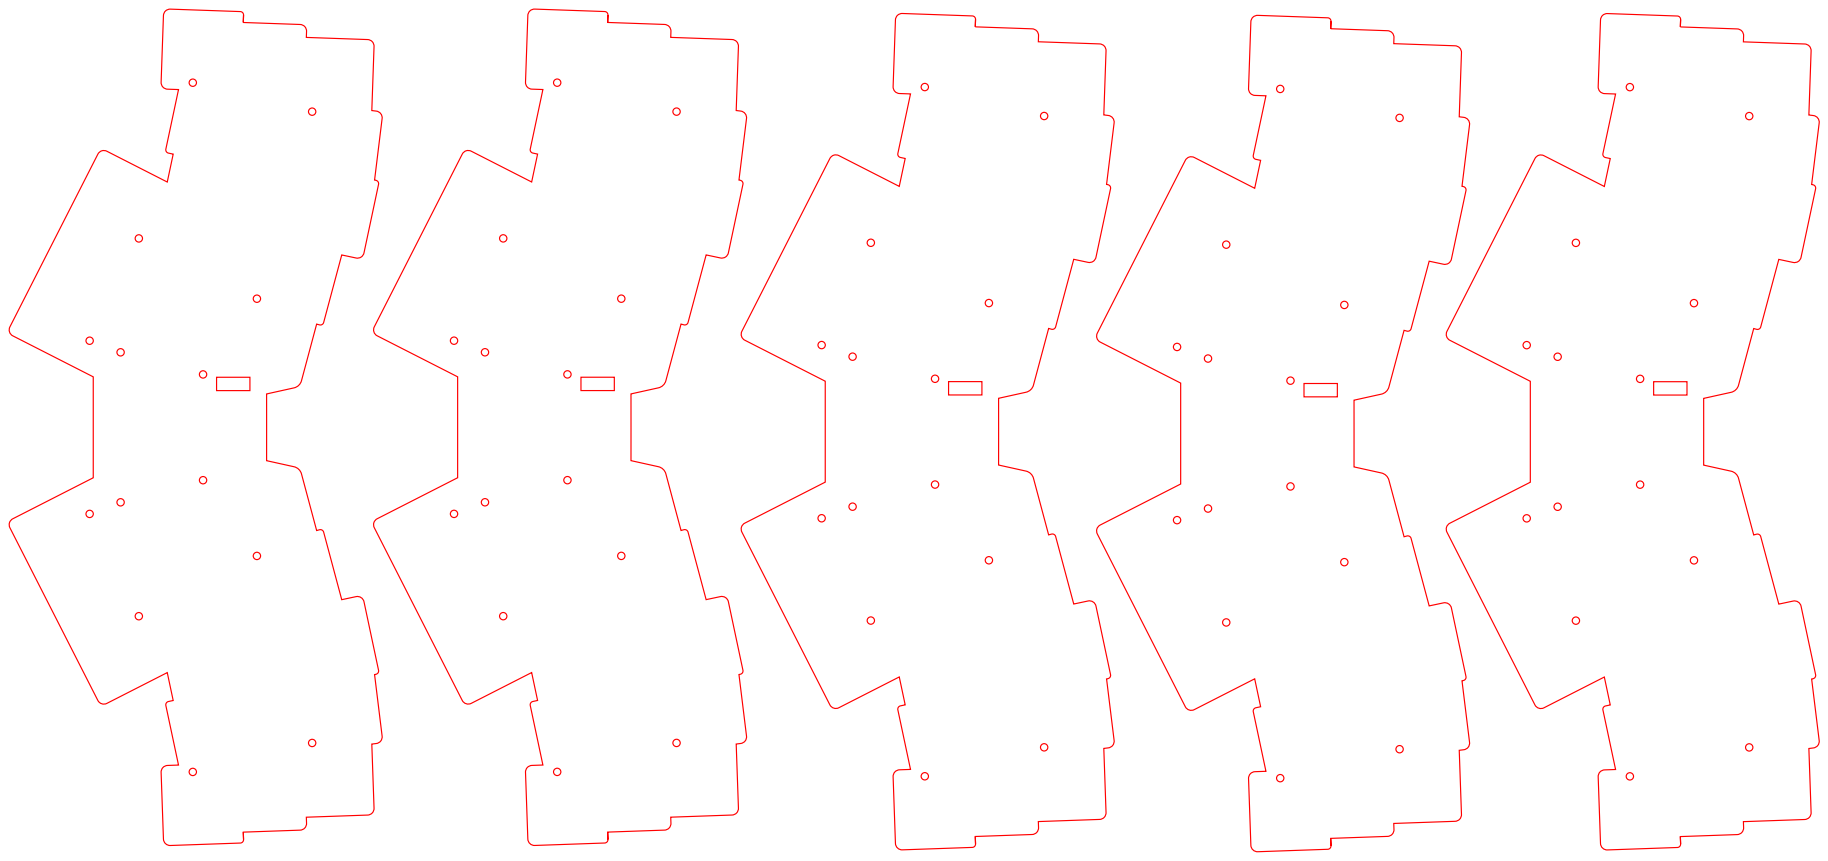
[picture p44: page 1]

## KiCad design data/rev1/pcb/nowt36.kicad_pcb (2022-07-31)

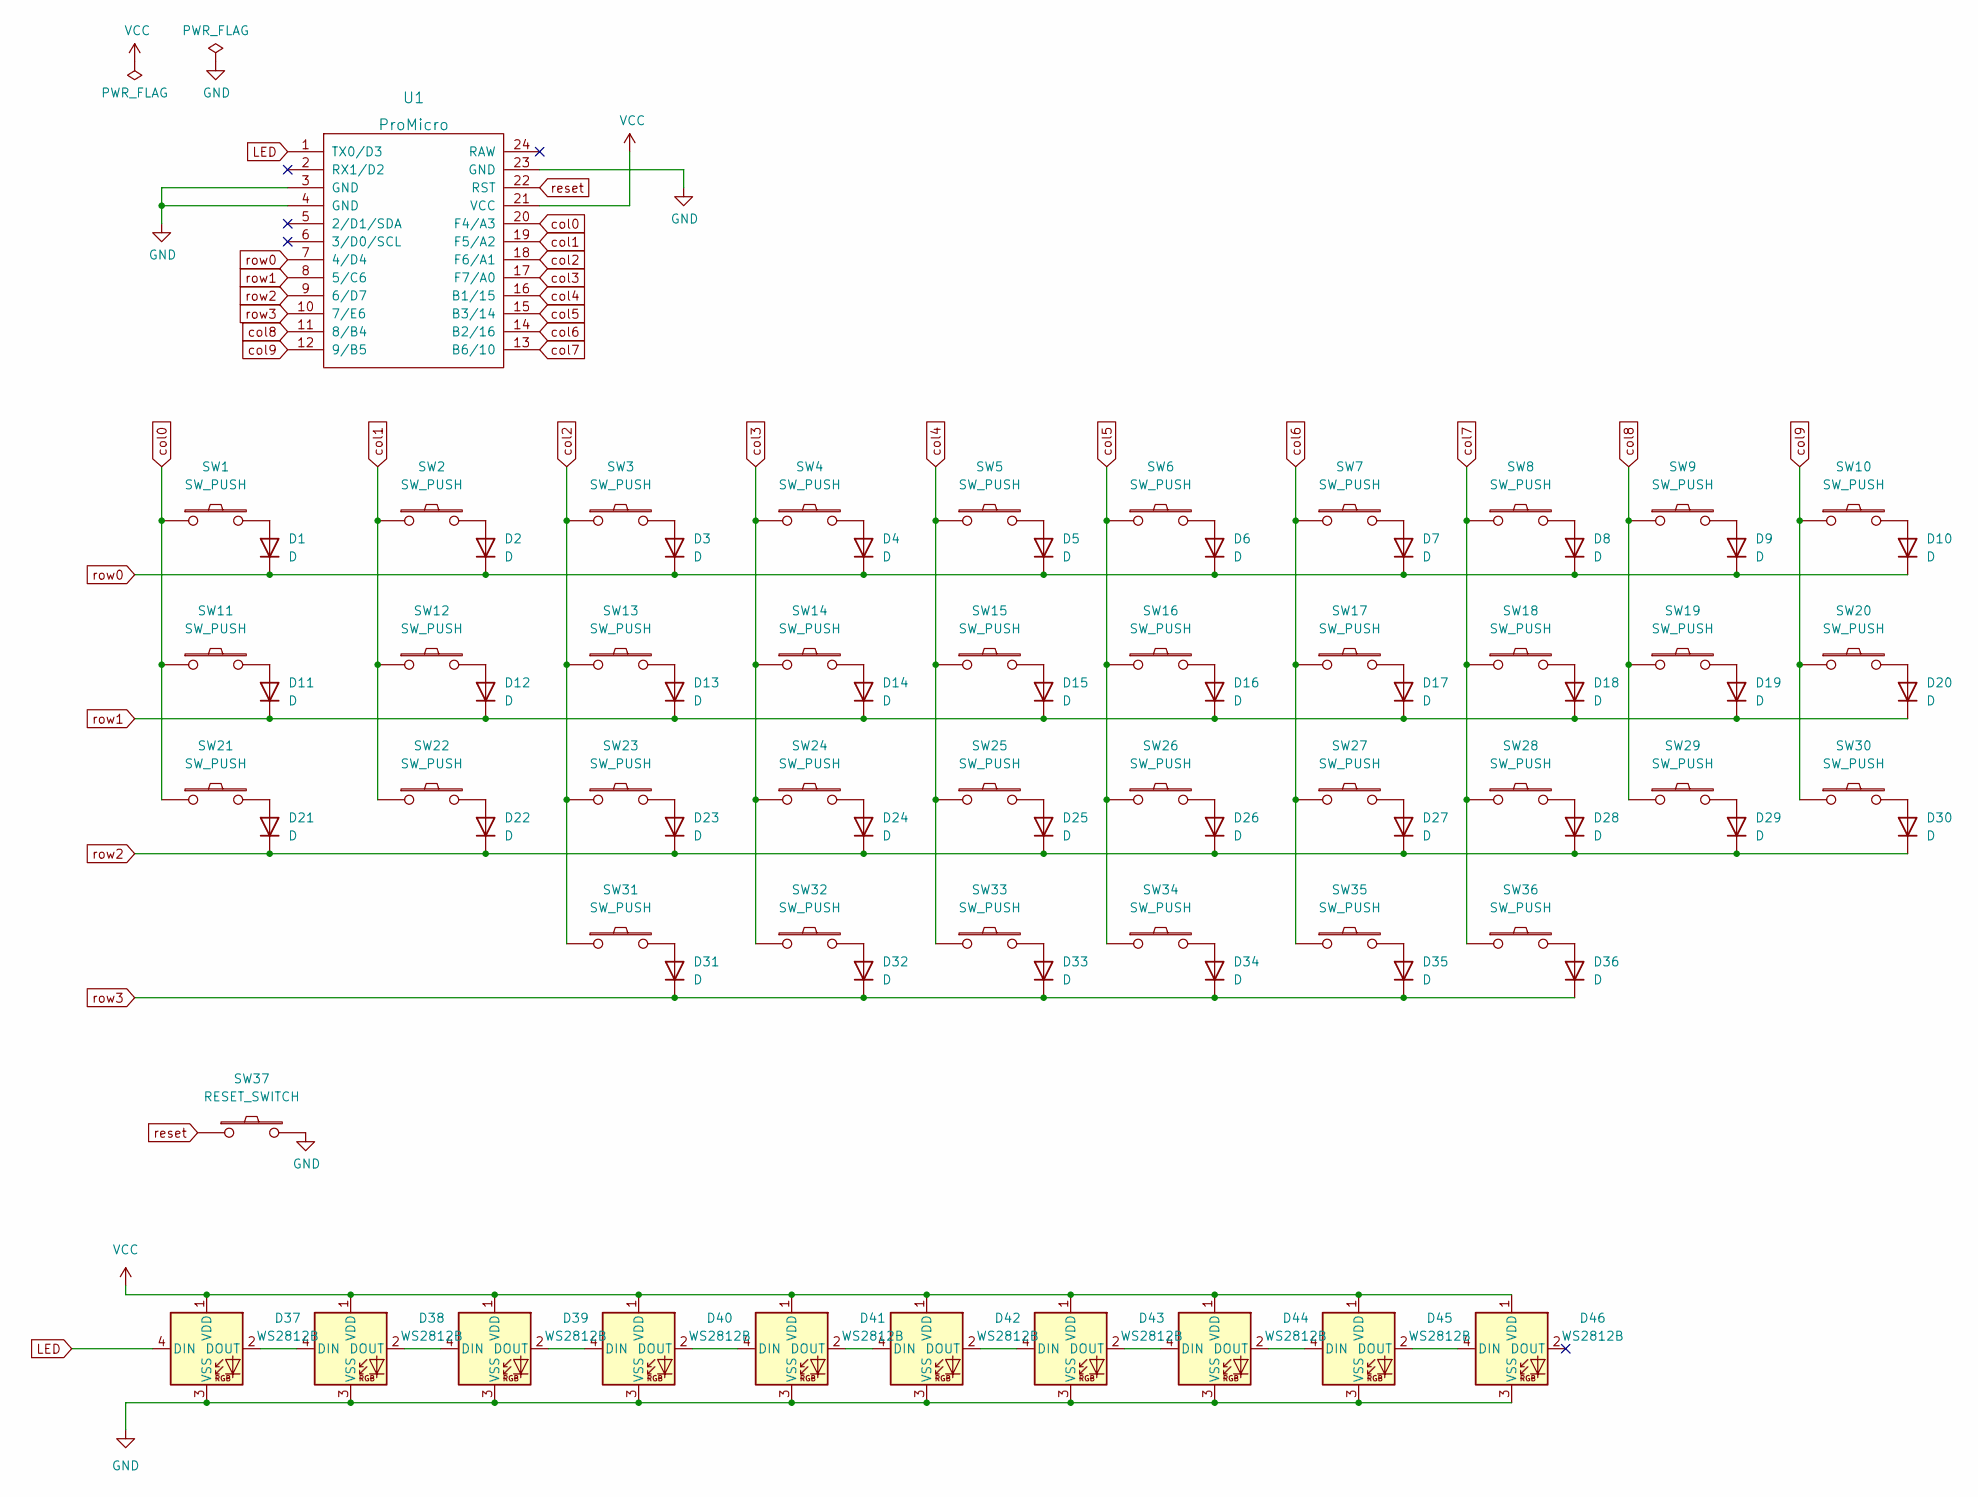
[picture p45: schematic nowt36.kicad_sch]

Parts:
D1, D2, D3, D4, D5, D6, D7, D8, D9, D10, D11, D12, D13, D14, D15, D16, D17, D18, D19, D20, D21, D22, D23, D24, D25, D26, D27, D28, D29, D30, D31, D32, D33, D34, D35, D36: D; Diode_SMD
D37, D38, D39, D40, D41, D42, D43, D44, D45, D46: WS2812B; LED_WS2812B_PLCC4_5.0x5.0mm_P3.2mm_Back
SW1, SW2, SW3, SW4, SW5, SW6, SW7, SW8, SW9, SW10, SW11, SW12, SW13, SW14, SW15, SW16, SW17, SW18, SW19, SW20, SW21, SW22, SW23, SW24, SW25, SW26, SW27, SW28, SW29, SW30, SW31, SW32, SW33, SW34, SW35, SW36: SW_PUSH; CherryMX_Hotswap
SW37: RESET_SWITCH; ResetSW_1side_back
U1: ProMicro; ProMicro_v3.5_mods

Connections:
GND: D37.3 (VSS), D38.3 (VSS), D39.3 (VSS), D40.3 (VSS), D41.3 (VSS), D42.3 (VSS), D43.3 (VSS), D44.3 (VSS), D45.3 (VSS), D46.3 (VSS), SW37.2, U1.3 (GND), U1.4 (GND), U1.23 (GND)
LED: D37.4 (DIN), U1.1 (TX0/D3)
unnamed: D1.2 (A), SW1.2
unnamed: D2.2 (A), SW2.2
unnamed: D3.2 (A), SW3.2
unnamed: D4.2 (A), SW4.2
unnamed: D5.2 (A), SW5.2
unnamed: D6.2 (A), SW6.2
unnamed: D7.2 (A), SW7.2
unnamed: D8.2 (A), SW8.2
unnamed: D9.2 (A), SW9.2
unnamed: D10.2 (A), SW10.2
unnamed: D11.2 (A), SW11.2
unnamed: D12.2 (A), SW12.2
unnamed: D13.2 (A), SW13.2
unnamed: D14.2 (A), SW14.2
unnamed: D15.2 (A), SW15.2
unnamed: D16.2 (A), SW16.2
unnamed: D17.2 (A), SW17.2
unnamed: D18.2 (A), SW18.2
unnamed: D19.2 (A), SW19.2
unnamed: D20.2 (A), SW20.2
unnamed: D21.2 (A), SW21.2
unnamed: D22.2 (A), SW22.2
unnamed: D23.2 (A), SW23.2
unnamed: D24.2 (A), SW24.2
unnamed: D25.2 (A), SW25.2
unnamed: D26.2 (A), SW26.2
unnamed: D27.2 (A), SW27.2
unnamed: D28.2 (A), SW28.2
unnamed: D29.2 (A), SW29.2
unnamed: D30.2 (A), SW30.2
unnamed: D31.2 (A), SW31.2
unnamed: D32.2 (A), SW32.2
unnamed: D33.2 (A), SW33.2
unnamed: D34.2 (A), SW34.2
unnamed: D35.2 (A), SW35.2
unnamed: D36.2 (A), SW36.2
unnamed: D37.2 (DOUT), D38.4 (DIN)
unnamed: D38.2 (DOUT), D39.4 (DIN)
unnamed: D39.2 (DOUT), D40.4 (DIN)
unnamed: D40.2 (DOUT), D41.4 (DIN)
unnamed: D41.2 (DOUT), D42.4 (DIN)
unnamed: D42.2 (DOUT), D43.4 (DIN)
unnamed: D43.2 (DOUT), D44.4 (DIN)
unnamed: D44.2 (DOUT), D45.4 (DIN)
unnamed: D45.2 (DOUT), D46.4 (DIN)
VCC: D37.1 (VDD), D38.1 (VDD), D39.1 (VDD), D40.1 (VDD), D41.1 (VDD), D42.1 (VDD), D43.1 (VDD), D44.1 (VDD), D45.1 (VDD), D46.1 (VDD), U1.21 (VCC)
col0: SW1.1, SW11.1, SW21.1, U1.20 (F4/A3)
col1: SW2.1, SW12.1, SW22.1, U1.19 (F5/A2)
col2: SW3.1, SW13.1, SW23.1, SW31.1, U1.18 (F6/A1)
col3: SW4.1, SW14.1, SW24.1, SW32.1, U1.17 (F7/A0)
col4: SW5.1, SW15.1, SW25.1, SW33.1, U1.16 (B1/15)
col5: SW6.1, SW16.1, SW26.1, SW34.1, U1.15 (B3/14)
col6: SW7.1, SW17.1, SW27.1, SW35.1, U1.14 (B2/16)
col7: SW8.1, SW18.1, SW28.1, SW36.1, U1.13 (B6/10)
col8: SW9.1, SW19.1, SW29.1, U1.11 (8/B4)
col9: SW10.1, SW20.1, SW30.1, U1.12 (9/B5)
reset: SW37.1, U1.22 (RST)
row0: D1.1 (K), D2.1 (K), D3.1 (K), D4.1 (K), D5.1 (K), D6.1 (K), D7.1 (K), D8.1 (K), D9.1 (K), D10.1 (K), U1.7 (4/D4)
row1: D11.1 (K), D12.1 (K), D13.1 (K), D14.1 (K), D15.1 (K), D16.1 (K), D17.1 (K), D18.1 (K), D19.1 (K), D20.1 (K), U1.8 (5/C6)
row2: D21.1 (K), D22.1 (K), D23.1 (K), D24.1 (K), D25.1 (K), D26.1 (K), D27.1 (K), D28.1 (K), D29.1 (K), D30.1 (K), U1.9 (6/D7)
row3: D31.1 (K), D32.1 (K), D33.1 (K), D34.1 (K), D35.1 (K), D36.1 (K), U1.10 (7/E6)

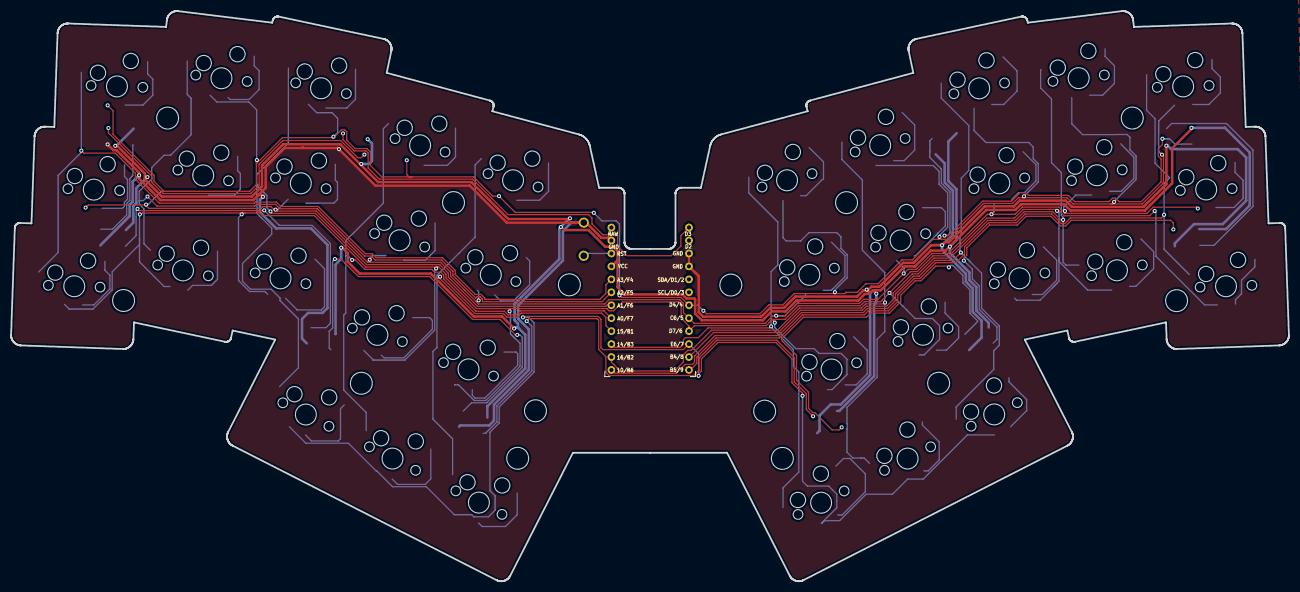
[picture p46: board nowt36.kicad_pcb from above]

Board: 2 copper layers, 250.7 x 111.8 mm, 98 parts (0 on the bottom side), 63 nets.

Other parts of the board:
HOLE1, HOLE2, HOLE3, HOLE4, HOLE5, HOLE6, HOLE7, HOLE8, HOLE9, HOLE10, HOLE11, HOLE12, HOLE13, HOLE14: Val**; M2_HOLE_v2_4.3mm

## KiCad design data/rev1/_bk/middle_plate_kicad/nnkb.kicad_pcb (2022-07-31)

Board: 2 copper layers, 48 parts (0 on the bottom side), 10 nets, no tracks yet.

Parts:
D37, D38, D39, D40, D41, D42, D43, D44, D45, D46: WS2812B; LED_WS2812B_PLCC4_5.0x5.0mm_P3.2mm_middle
SW1, SW2, SW3, SW4, SW5, SW6, SW7, SW8, SW9, SW10, SW11, SW12, SW13, SW14, SW15, SW16, SW17, SW18, SW19, SW20, SW21, SW22, SW23, SW24, SW25, SW26, SW27, SW28, SW29, SW30, SW31, SW32, SW33, SW34, SW35, SW36: SW_PUSH; CherryMX_Hotswap_middle
SW37: RESET_SWITCH; ResetSW_1side_back_middle
U1: ProMicro; ProMicro_v3.5_mods_middle

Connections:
col0: SW1.1, SW11.1, SW21.1
col1: SW2.1, SW12.1, SW22.1
col2: SW3.1, SW13.1, SW23.1, SW31.1
col3: SW4.1, SW14.1, SW24.1, SW32.1
col4: SW5.1, SW15.1, SW25.1, SW33.1
col5: SW6.1, SW16.1, SW26.1, SW34.1
col6: SW7.1, SW17.1, SW27.1, SW35.1
col7: SW8.1, SW18.1, SW28.1, SW36.1
col8: SW9.1, SW19.1, SW29.1
col9: SW10.1, SW20.1, SW30.1

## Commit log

2022-07-16 ビルドガイドを修正
2022-07-16 docs: README を更新
2022-07-17 シリコンカットサポートシートを追加
    [nowt.FCStd]
2022-07-18 ビルドガイド更新
    [nowt.FCStd]
2022-07-18 ビルドガイド修正
2022-07-20 middle upper 修正
    [middle_upper.dxf, nowt.FCStd]
2022-07-24 遊舎工房用のデータを追加した
2022-07-31 rev0.7.6 に移動
    [313x255_bottom_middle_plate.dxf, base.dxf, middle_upper.dxf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]
2022-07-31 rev1 を追加
    [nnkb.kicad_pcb, nnkb.kicad_sch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]
2022-08-28 rev0.7.6を削除
    [313x255_bottom_middle_plate.dxf, base.dxf, middle_upper.dxf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]
2022-08-28 ビルドガイドを追加
    [plate_base.dxf]
2022-08-28 データの配置ヲ修正
2022-08-28 Remap でのファームウェアの書き込みに対応
2022-08-28 fix リンクを修正
2022-08-28 シリコンシートカットの画像を追加、修正
2022-08-28 ミドルプレートのzipをダウンロードできるように修正
2022-08-29 画像を修正
2022-08-29 なぜか画像の反映がされないため、ちょっと修正
2022-09-03 ライセンスを CC BY に変更
2022-09-03 不要なデータを削除
2022-09-09 遊舎工房のミドルプレートのリンクを更新
2022-09-14 画像の追加
2022-09-14 画像変更

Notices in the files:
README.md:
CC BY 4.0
